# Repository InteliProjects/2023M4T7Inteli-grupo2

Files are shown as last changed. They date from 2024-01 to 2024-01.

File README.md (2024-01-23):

# Inteli - Instituto de Tecnologia e Liderança 

<p align="center">
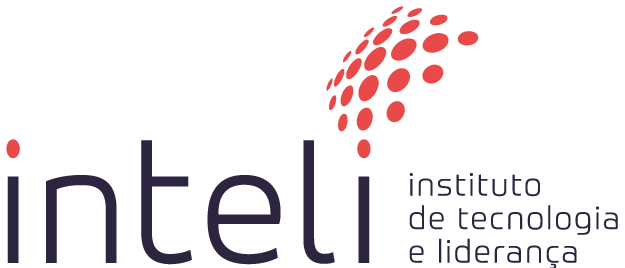
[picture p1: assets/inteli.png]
Inteli - Instituto de Tecnologia e Liderança

</p>

<br>

# Jin

## JinWar

## 👨‍🎓 Integrantes: 
- <a href="https://www.linkedin.com/in/drielly-farias/">Drielly Farias</a>
- <a href="https://www.linkedin.com/in/diogo-pelaes-a34593279/">Diogo Burgierman</a>
- <a href="https://www.linkedin.com/in/eduardo-hos/">Eduardo Henrique Oliveira Santos</a>
- <a href="https://www.linkedin.com/in/enzo-bressane-72a030219/">Enzo Schiezaro Bressane</a> 
- <a href="https://www.linkedin.com/in/isabelle-beatriz-vasquez-oliveira-55a19626a/">Isabelle Beatriz Vasquez Oliveira</a>
- <a href="https://www.linkedin.com/in/ricardo-novaes-24276b271/">Ricardo Novaes</a>

## 👩‍🏫 Professores:
### Orientador(a) 
- <a href="https://www.linkedin.com/in/profclaudioandre/">Claudio André</a>
### Instrutores
- <a href="https://www.linkedin.com/in/aila-esteque/">Aila Esteque</a>
- <a href="https://www.linkedin.com/in/andre-godoi-chiovato-83730228/">André Godoi</a> 
- <a href="https://www.linkedin.com/in/andreluizbraga/">André Braga</a> 
- <a href="https://www.linkedin.com/in/fabiana-martins-de-oliveira-8993b0b2/">Fabiana Martins de Oliveira</a>
- <a href="https://www.linkedin.com/in/fatima-toledo/">Fátima Toledo</a> 
- <a href="https://www.linkedin.com/in/geraldo-magela-severino-vasconcelos-22b1b220/">Geraldo Vasconcelos</a>
- <a href="https://www.linkedin.com/in/laizaribeiro/">Laíza Ribeiro</a>
## 📜 Descrição
&emsp;&emsp;O projeto da Alma Sírio-Libanês visa desenvolver e implementar um sistema avançado de rastreamento e gestão de movimentos para pacientes e equipes de cuidado dentro do hospital, utilizando tecnologias de localização e Internet das Coisas (IoT). A iniciativa é concentrada principalmente nas unidades de pronto-atendimento em São Paulo e Brasília, envolvendo toda a extensa rede de colaboradores e o corpo clínico do Hospital Sírio-Libanês.

&emsp;&emsp;A solução proposta busca oferecer um controle mais preciso e em tempo real da localização de pacientes e profissionais dentro da instituição, visando otimizar o fluxo de atendimento, reduzir gargalos operacionais e melhorar a eficiência dos serviços prestados, especialmente em situações de emergência. O sistema contará com etiquetas eletrônicas atribuídas aos indivíduos, permitindo sua identificação imediata, localização precisa e rastreamento de movimentos.

&emsp;&emsp;Para garantir o sucesso do projeto, uma série de fases de validação serão implementadas, abrangendo aspectos técnicos e operacionais. A intenção é assegurar que o sistema não apenas funcione corretamente do ponto de vista técnico, mas que também atenda às necessidades reais do hospital, contribuindo efetivamente para a melhoria dos processos internos.

&emsp;&emsp;O MVP (Produto Mínimo Viável) consistirá em uma ferramenta de gestão de localização de pessoas, que deverá cumprir uma série de requisitos essenciais, incluindo a identificação do portador da etiqueta e seu papel dentro da instituição, fornecimento de localização em tempo real, avaliação de tempos de permanência em áreas específicas, possibilidade de resposta a emergências e recebimento de informações críticas, além da avaliação de tempos de resposta a emergências. O dispositivo associado é ser portátil, resistente e fácil de manipular.

[Aqui](https://youtu.be/W80r4j70KOY) é possível acessar o link do vídeo com a demonstração da solução Jinwar.

[Aqui](https://miro.com/welcomeonboard/U0x3RXdwbGt4dHk1anlPYnpDbzl5alZtdFVXVk9NbmNHNzBNT25CQWt2MUxkbGhlQU9VMTM3Y2lqRUU2cFdZeHwzNDU4NzY0NTQ1NjY5NzM5MDc0fDI=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) é possível acessar o link do Lean Inceeption

## 📁 Estrutura de pastas

Dentre os arquivos e pastas presentes na raiz do projeto, definem-se:

- <b>assets</b>: aqui estão os arquivos relacionados a parte gráfica do projeto, ou seja, as imagens e vídeos que os representam (O logo do grupo pode ser adicionado nesta pasta).

- <b>document</b>: aqui estão todos os documentos do projeto, incluindo o manual de instruções (se aplicável). Há também uma pasta denominada <b>outros</b> onde estão presentes outros documentos complementares.

- <b>src</b>: Todo o código fonte criado para o desenvolvimento do projeto, incluindo firmware, notebooks, backend e frontend, se aplicáveis.

- <b>README.md</b>: arquivo que serve como guia e explicação geral sobre o projeto (o mesmo que você está lendo agora).

## 🔧 Instalação

Para utilizar a solução Jin, é ncessário ter acesso à:
- Arduino IDE (disponível no site :https://www.arduino.cc/en/software)
- Ubidots (disponível em Ubidots.com)
- 
  Em caso de dúvida sobre como instalar ou navegar por alguma das plataformas, consulte a seção 3 do manual de instruções.

**Manual de Instruções**: https://github.com/2023M4T7Inteli/grupo2/blob/main/document/Manual%20de%20Instru%C3%A7%C3%B5es%20-%20Jinwar.pdf

## 🗃 Histórico de lançamentos
* 0.0.1 - 27/10/2023
    Adição das seções 1, 3.1 correspondente à Entendimento do negócio

* 0.0.2 - 27/10/2023
    Adição das seção 3.2 correspondente à experiência de usuário

* 0.0.3 - 27/10/2023
    Adição da seção 3.4.1 correspondente ao Protótipo inicial do projeto usando o simulador wokwi

* 0.0.4 - 27/10/2023
    Adição da seção 3.3.1 correspondente aos Requisitos Funcionais

* 0.1.1 - 10/11/2023
    Adição da seção 3.2.4 correspondente a Prototipagem rápida da solução

* 0.1.2 - 10/11/2023
        Adição da seção 3.4.2 correspondente ao Protótipo físico do projeto (offline)

* 0.1.3 - 10/11/2023
        Adição da seção 3.2.2 correspondente aos Requisitos não funcionais

* 0.2.1 - 24/11/2023
        Adição da seção 3.4.3 correspondente ao Protótipo do Projeto com MQTT e I2C

* 0.2.2 - 24/11/2023
        Adição da seção 2 correspondente a metodologia RM-ODP

* 0.2.3 - 29/11/2023
        Adição da seção 3.3.4 correspondente a arquitetura técnica da solução

* 0.3.1 - 08/12/2023
        Adição da seção 3.4.4 correspondente a Protótipo Físico do Projeto (online)

* 0.3.2 - 08/12/2023
        Adição do código do projeto

* 0.3.3 - 08/12/2023
        Adição da seção 3.3.5 correspondente a Arquitetura do Protótipo

* 0.3.4 - 08/12/2023
        Adição do Manual de Instruções

* 0.3.4 - 08/12/2023
        Adição da seção 3.3.5 correspondente às Possibilidades de Descarte

* 0.4.1 - 21/12/2023
        Adição da seção 3.4.5 correspondente ao Protótipo Final do Projeto

* 0.4.2 - 21/12/2023
        Adição da versão final do código

* 0.4.3 - 21/12/2023
        Adição da seção 3.3.6 correspondente a Arqitetura Refinada da Solução

* 0.4.4 - 21/12/2023
        Atualização do Manual de Instruções

* 0.4.5 - 21/12/2023
        Revisão e ajustes finais

## 📋 Licença/License

<p xmlns:cc="http://creativecommons.org/ns#" xmlns:dct="http://purl.org/dc/terms/">
    <a property="dct:title" rel="cc:attributionURL" href="https://github.com/2023M4T7Inteli/grupo2">Jinwar</a> by 
    <span property="cc:attributionName">
        <a href="https://www.linkedin.com/in/diogo-pelaes-a34593279/">Diogo Burgierman</a>, 
        <a href="https://www.linkedin.com/in/drielly-farias/">Drielly Farias</a>, 
        <a href="https://www.linkedin.com/in/eduardo-hos/">Eduardo Henrique Oliveira Santos</a>, 
        <a href="https://www.linkedin.com/in/enzo-bressane-72a030219/">Enzo Schiezaro Bressane</a>,
        <a href="https://www.linkedin.com/in/isabelle-beatriz-vasquez-oliveira-55a19626a/">Isabelle Beatriz Vasquez Oliveira</a>, 
        <a href="https://www.linkedin.com/in/ricardo-novaes-24276b271/">Ricardo Novaes</a>
    </span> 
    is licensed under 
    <a href="http://creativecommons.org/licenses/by/4.0/?ref=chooser-v1" target="_blank" rel="license noopener noreferrer" style="display:inline-block;">
        Attribution 4.0 International
        
        
    </a>
</p>

## 🎓 Referências

Aqui estão as referências usadas no projeto:
1. ROCHA, YB. **Jinwar: a vila criada por e para mulheres no Curdistão.** 18 maio 2018. Disponível em: https://www.brasildefato.com.br/2018/05/10/jinwar-a-vila-criada-por-e-para-mulheres-no-curdistao. Acesso em: 23 out. 2023.

2. LUIZ, Jonathan. **Hospitais particulares que não prestam atendimento emergencial comentem crime.** 5 out. 2020. Disponível em: https://www.correiobraziliense.com.br/cidades-df/2020/10/4880013-direito-do-consumidor.html. Acesso em: 23 out. 2023.

3. CASAROTTO, C. (2020, 11 de dezembro). **As 5 forças de Porter: quais são elas e como entender o conjunto de fatores que influenciam no sucesso do seu negócio? rockcontent.** Disponível em: https://rockcontent.com/br/blog/5-forcas-de-porter/
   Acesso em: 24 out. 2023.

4. .RAEBURN, A. (2022, 28 de novembro). **Análise SWOT/FOFA: o que é e como usá-la (com exemplos).** asana. Disponível em: https://asana.com/pt/resources/swot-analysis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 Acesso em: 22 out. 2023.

5. SOFTWARE, Lucid. **Redirecting**. Disponível em: https://www.lucidchart.com/pages/pt/o-que-e-analise-swot. Acesso em: 24 out. 2023.

6. OSTERWALDER, A.; PIGNEUR, Y.; BERNARDES, G.; SMITH, **A. Value Proposition Design: How to Create Products and Services Customers Want. New Jersey: Wiley, 2014.4**. Acesso em: 24 out. 2023.

7. ESFERA ENERGIA. (2022, 14 de outubro). **Matriz de risco: o que é, quando usar e como montar uma tabela**. esferablog. Disponível em: https://blog.esferaenergia.com.br/gestao-empresarial/matriz-de-risco. Acesso em: 25 out. 2023.

8. ALBERTACCI, Laura. **Devo me preocupar com a LGPD?** Jus.com.br. Disponível em: https://jus.com.br/artigos/91636/devo-me-preocupar-com-a-lgpd. Acesso em: 18 out. 2023.

9. SÍRIO-LIBANÊS, Hospital. **Hospital Sírio Libanês**. 8 fev. 2021. Disponível em: https://hospitalsiriolibanes.org.br/politica-de-privacidade/. Acesso em: 18 out. 2023.

10. Salminen, J., Nielsen, L., Bahloul, M. et al. **Persona preparedness: a survey instrument for measuring the organizational readiness for deploying personas.** Inf Technol Manag (2022). Disponível em: https://doi.org/10.1007/s10799-022-00373-9 Acesso em: 19 out. 2023.

11. SIQUEIRA, A. (2022, 14 de fevereiro). **Persona: o que é, como definir e por que criar uma para sua empresa [+ exemplos práticos e um gerador].** Resultados Digitais. Disponível em: https://resultadosdigitais.com.br/marketing/persona-o-que-e/#:~:text=O%20que%20é%20persona?,,%20objetivos,%20desafios%20e%20preocupações. Acesso em: 25 out. 2023.

12. SÍRIO-LIBANÊS, Hospital. **Hospital Sírio-Libanês**. Disponível em: https://www.hospitalsiriolibanes.org.br/encontre-seu-medico/. Acesso em: 19 out. 2023.

13. SAÚDE, Portal Setor. **A definição de valor em saúde do Sírio-Libanês e os desafios dos setores público e privado - Setor Saúde.** 7 maio 2019. Disponível em: https://setorsaude.com.br/a-definicao-de-valor-em-saude-do-sirio-libanes-e-os-desafios-dos-setores-publico-e-privado/. Acesso em: 19 out. 2023.

14. SÍ­RIO-LIBANÊS, Hospital. **Hospital Sí­rio-Libanês.** Disponível em: https://www.hospitalsiriolibanes.org.br/especialidades-medicas/sao-paulo/hernia-e-parede-abdominal/. Acesso em: 19 out. 2023.

15. BRASIL, Hospitais. **Sírio-Libanês cria nova marca para fomentar tecnologia, dados e inovação na saúde e ensino.** 16 dez. 2022. Disponível em: https://portalhospitaisbrasil.com.br/sirio-libanes-cria-nova-marca-para-fomentar-tecnologia-dados-e-inovacao-no-setor-de-saude-e-ensino/. Acesso em: 19 out. 2023.

16. SÍRIO-LIBANÊS, **Hospital. Experiência Sírio-Libanês | Sírio-Libanês Ensino e Pesquisa.** Disponível em: https://iep.hospitalsiriolibanes.org.br/experiencia-sirio-libanes. Acesso em: 19 out. 2023.

17. SÍRIO-LIBANÊS, Hospital. **Especialização em Experiência do Paciente e Cuidado Centrado na Pessoa | Hospital Sírio-Libanês.** Disponível em: https://iep.hospitalsiriolibanes.org.br/cursos-pos-graduacao/especializacao-em-experiencia-do-paciente-e-cuidado-centrado-na-pessoa. Acesso em: 26 out. 2023.

18. GIBBONS, Sarah. **Journey Mapping 101.** 9 dez. 2018. Disponível em: https://www.nngroup.com/articles/journey-mapping-101/. Acesso em: 24 out. 2023.

19. TEAM, Vyond. **What Is A Storyboard & How Do You Create One? (With Video)**. 11 jan. 2023. Disponível em: https://www.vyond.com/resources/what-is-a-storyboard-and-why-do-you-need-one/. Acesso em: 19 out. 2023.

20. ARRUDA, Ricardo. **O que são User Stories (Estórias de Usuário)? - Agile Expert**. 14 maio 2021. Disponível em: https://www.agilexpert.com.br/2021/05/14/o-que-sao-user-stories-historias-de-usuario/. Acesso em: 25 out. 2023.

21. ECOASSIT. **Quais impactos o lixo eletrônico causa no planeta?** - Ecoassist. Disponível em: https://ecoassist.com.br/quais-impactos-o-lixo-eletronico-causa-no-planeta/. Acesso em: 30 nov. 2023.

22. FERREIRA, Thalita.**Quais são os impactos dos resíduos Eletrônicos no Meio Ambiente.** 15 set. 2022. Disponível em: https://matanativa.com.br/impactos-dos-residuos-eletronicos-no-meio-ambiente/#:~:text=Efeitos%20nocivos%20à%20saúde%20humana,de%20pulmão;%20e%20câncer%20linfático. Acesso em: 30 nov. 2023.

23. MARTINS, Alejandra. **O metal pesado tóxico que afeta crianças no Brasil e no mundo décadas após proibição - BBC News Brasil.** 20 jul. 2021. Disponível em: https://www.bbc.com/portuguese/geral-57886448. Acesso em: 5 dez. 2023.

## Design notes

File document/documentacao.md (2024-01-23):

# Documentação IoT - Módulo 4 - Inteli

## JinWar

#### <a href="https://www.linkedin.com/in/drielly-farias/">Drielly Farias</a>, <a href="https://www.linkedin.com/in/diogo-pelaes-a34593279/">Diogo Burgierman</a>, <a href="https://www.linkedin.com/in/eduardo-hos/">Eduardo Henrique Oliveira Santos</a>, <a href="https://www.linkedin.com/in/enzo-bressane-72a030219/">Enzo Bressane</a>, <a href="https://www.linkedin.com/in/isabelle-beatriz-vasquez-oliveira-55a19626a/">Isabelle Vasquez</a>, <a href="https://www.linkedin.com/in/ricardo-novaes-24276b271/">Ricardo B Novaes</a>

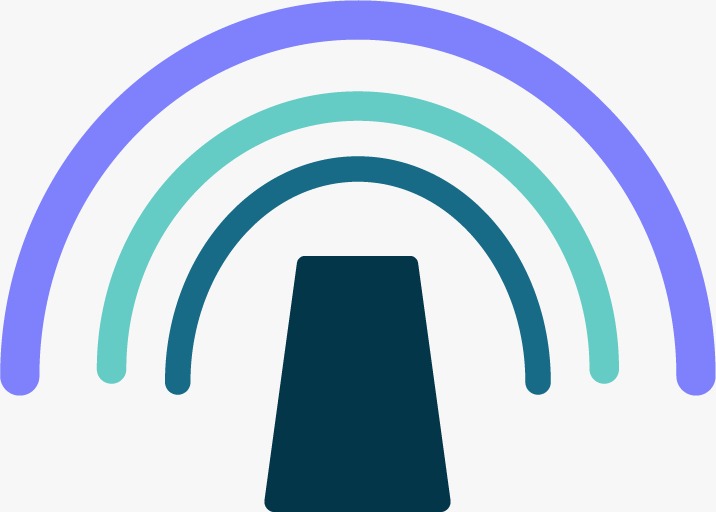
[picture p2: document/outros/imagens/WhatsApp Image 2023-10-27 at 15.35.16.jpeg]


## Sumário

[1. Introdução](#c1)

[2. Metodologia](#c2)

[3. Desenvolvimento e Resultados](#c3)

[4. Possibilidades de Descarte](#c4)

[5. Conclusões e Recomendações](#c5)

[6. Referências](#c6)

<br>

# 1. Introdução

&emsp;&emsp;Este texto descreve o contexto, desenvolvimento e evolução do projeto do grupo JinWar, o qual visa coletar, organizar e fornecer a localização de pessoas dentro do ambiente do hospital Sírio Libanês. Além de questões técnicas, são apresentadas também informações sobre a análise de negócios da empresa.

&emsp;&emsp;O hospital Sírio-Libanês começou em 1921 com um grupo de mulheres e, ao longo de mais de um século, se consolidou como hospital de referência. Atualmente é uma instituição de grande porte, com atuação na área de saúde e inovação médica, com unidades em São Paulo e Brasília.

&emsp;&emsp;A Alma Sírio-Libanês, uma divisão do Hospital Sírio Libanês com foco em tecnologia e inovação, propôs o desenvolvimento de uma solução baseada em IoT, para coletar e fornecer a localização da equipe assistencial e dos pacientes, a fim de alocar atividades e funcionários com maior eficiência. O grupo JinWar pretende solucionar a questão usando componentes de hardware e a linguagem de programação C++.

&emsp;&emsp;O grupo Jinwar¹, o qual realizou esse projeto, escolheu esse nome para representá-los por significar de acordo com uma tradução livre do dialeto curdo, kurmanji, “o espaço de vida”. Além disso, esse é o mesmo nome de uma cidade só de mulheres e crianças que busca se afastar dos conflitos.

&emsp;&emsp;A cidade é uma forma de manifestação e resposta a violência de homens jugos em conflitos na Síria. Como o Sirio-Libanês foi uma forma de gratidão de mulheres sirio-libanesas ao que a cidade de São Paulo proporcionou a elas, e que até hoje acolhe pessoas, Jinwar também é uma manifestação de acolhimento a essas famílias de mulheres que buscam se erguer com seus filhos no meio de um grande ato de sororidade. O grupo Jinwar compartilha desse mesmo espírito e busca criar um ambiente seguro, onde os indivíduos possam recorrer para cuidar de sua saúde e bem-estar.

## 1.1 Objetivos

&emsp;&emsp;O hospital deseja como objetivo geral otimizar a alocação da equipe assistencial e dos pacientes nos locais de pronto-atendimento. Desse modo, pretende-se criar um dispositivo wearable capaz de informar a localização de profissionais, com foco na equipe de enfermagem, médicos e fisioterapeutas mais próximos do paciente que precisa de assistência, de forma rápida e eficiente. Sendo mais específico, a localização poderá ser feita por meio de um crachá que auxiliaria na otimização. O dispositivo também permitirá ter uma visão macro da localização da equipe do hospital no Pronto Atendimento (PA), para então priorizar e reordenar os demais tipos de atendimentos, como consultas e exames.

## 1.2 Proposta da solução

&emsp;&emsp;A solução para o problema descrito será um sistema com o uso de uma tag com RFID (Radio Frequency Identification), usando uma placa Arduino EESP 32, um kit RFID-RC522 e uma interface para visualização dos dados coletados.
Esses componentes de hardware serão integrados usando a linguagem de programação C++ e C.

## 1.3 Justificativa

&emsp;&emsp;O sistema Jinwar otimiza o atendimento e dinâmica diária no hospital ao acelerar a troca de informações entre equipes e centralizar as informações de localização disponíveis em um único lugar. A agilidade que o Jinwar proporciona permite direcionar o fluxo de atendimento do paciente e diminuir o tempo de resposta por parte da equipe médica. Além disso, possui baixo custo de implementação. O foco macro do projeto visa conseguir preservar a vida. Com os benefícios que esse projeto traz, o Hospital Sirio-Libanês, com a sua vertical de inovação Alma - Sirio-Libanês poderá ser uma solução única feita pensada para auxiliar a equipe médica que precisa ser objetiva no atendimento. Pontos como o estacionamento do hospital não são passíveis de obter a localização precisa sobre onde o paciente está ou sobre onde a equipe do hospital está para auxiliar. Com essa solução, esse tipo de problema, caso venha a acontecer, não terá empecilhos por falta de alcance.

# 2. Metodologia

&emsp;&emsp;O Modelo de Referência para Arquitetura Orientada a Objeto, ou RM-ODP (Reference Model for Open Distributed Processing) é um framework padronizado que define uma abordagem para o design de sistemas complexos, como projetos de IoT em grande escala. Ele foca em aspectos como estrutura, comportamento e interações entre diferentes partes de um sistema. O RM-ODP destaca-se por sua abordagem abrangente e flexível na descrição de arquiteturas de sistemas. Sua padronização, aceita por organizações de referência, promove a consistência e interoperabilidade em ambientes que adotam esse modelo. Além disso, o modelo é especialmente adequado para a programação orientada a objetos, sendo uma escolha ideal para projetos de IoT.

&emsp;&emsp;Na execução de cada etapa da metodologia aplicada, é fundamental evidenciar os seguintes pontos:

- **Ponto de Vista da Empresa:** Foca na identificação dos requisitos do negócio, objetivos, e políticas organizacionais. Esta etapa é crucial para compreender o contexto dentro do qual o sistema irá operar e os objetivos que ele visa atingir. Neste ponto, definimos a proposta de solução seguindo os objetivos da instituição e as prioridades do cliente. A análise feita para decidir esses pontos foi feita a partir de análises de negócios como Canvas Proposta de Valor, Análise SWOT, 5 Forças de Porter e Matriz de Riscos, com o objetivo de entender como a solução vai impactar nos processos do hospital e as melhores formas de otimizar os mesmos.

- **Ponto de Vista da Informação:** Concentra-se na estrutura e no fluxo de informações dentro do sistema. Esta etapa envolve a modelagem dos tipos de dados que o sistema irá processar, bem como as regras e restrições sobre esses dados. Para isso, o grupo buscou entender como os dados são distribuídos atualmente e como será esse fluxo de informações na solução. Essa análise envolveu coletar informações sobre requisitos para a gestão de informação, estrutura de dados e interface.

- **Ponto de Vista da Computação:** Esta etapa aborda a funcionalidade do sistema, definindo os componentes de software que irão realizar as operações e processos necessários. Inclui a modelagem das interfaces e a interação entre os componentes se software e hardware. Para isso, definimos os componentes de hardware essenciais e como o ESP32, sensores de RFID e Tokens de RFID, além de outros componentes relacionados aos mesmos. Por outro lado, entre os componentes de software essenciais estão o uso do protocolo de comunicação MQTT para possibilitar a comunicação e alta velocidade de resposta entre os componentes da solução.

- **Ponto de Vista da Engenharia:** Foca na infraestrutura necessária para suportar a distribuição do sistema. Esta etapa lida com a arquitetura do sistema em termos de componentes de software e hardware, comunicação de rede, e mecanismos de controle e gerenciamento. No desenvolvimento do projeto, o grupo definiu os componentes de hardware na seção de Bill Of Materials e definiu o Ubdots como uma plataforma necessária para realizar a comunicação de rede entre os componentes físicos e o software já que a plataforma Ubidots proporciona uma integração rápida, possibilitando uma interação com a solução por meio de uma interface de forma prática. Além disso, foram definidas abordagens para o desenvolvimento e implementação, incorporando as particularidades da solução sugerida.

- **Ponto de Vista da Tecnologia:** Esta etapa envolve a seleção de tecnologias específicas, ferramentas e plataformas que serão utilizadas na implementação do sistema. Inclui a escolha de linguagens de programação, sistemas de banco de dados, hardware, e outras tecnologias relevantes. No caso do projeto desenvolvido pelo grupo Jinwar, foram selecionadas tecnologias como o ESP32, RFID, MQTT que serão implementadas por outros componentes de hardware e por códigos desenvolvidos na linguagem C++. Para realizar essa decisão, foi analisada a viabilidade de infraestruturas de redes e as melhores opções de protocolos de comunicação, pensando tanto na funcionalidade quanto na segurança no contexto de localização de pessoas em um ambiente hospitalar.

&emsp;&emsp;Esses cinco pontos de vista da **RM-ODP** oferecem uma estrutura abrangente para o planejamento e design de sistemas distribuídos, assegurando que todos os aspectos críticos, desde os objetivos de negócios até as escolhas tecnológicas, sejam cuidadosamente considerados e integrados.

&emsp;&emsp;É crucial ressaltar que este modelo é independente de tecnologia. As descrições de arquitetura no RM-ODP são conceituais e não estão vinculadas a tecnologias específicas, o que favorece a adaptabilidade do sistema ao longo do tempo. Todos esses motivos levaram o grupo Jimwar a adotar o modelo RM-ODP no desenvolvimento da solução IoT para o Hospital Sírio-Libanês.

# 3. Desenvolvimento e Resultados

&emsp;&emsp; Nesta seção, encontra-se o registro de desenvolvimento do projeto, documentando as informações sobre a análise de negócios, sobre o design da experiência do usuário e os resultados obtidos a partir desse estudo juntamente com a aplicação dos conhecimentos técnicos.

## 3.1. Domínio de Fundamentos de Negócio

&emsp;&emsp;Nesta seção, busca-se entender qual é o contexto do projeto e da indústria, onde Alma Sirio Libanes se situa no mercado, apresentando a solução, seus pontos que agregam valor, no que ela se diferencia, buscando ter uma visão micro e ao mesmo tempo macro do parceiro e da solução. Dessa maneira, a solução Jinwar poderá ser construída com mais segurança, se preparando para eventuais problemas, oportunidades, e até mesmo, para como serão tratados os dados dos pacientes e equipe do hospital.

### 3.1.1. Contexto da Indústria

&emsp;&emsp;Nos últimos anos, a indústria de saúde no Brasil tem passado por grandes transformações, tanto no que se refere à inovação tecnológica quanto na redefinição do foco do atendimento, ao mesmo tempo em que enfrenta desafios constantes relacionados às regulamentações governamentais.

&emsp;&emsp;É inegável que a indústria de hospitais particulares no Brasil tem experimentado um notável crescimento, o que gera uma competição acirrada entre as principais empresas do setor e uma busca crescente por vantagens competitivas. No cenário atual, a inovação tecnológica se tornou o pilar central dessa expansão, implicando a necessidade de mais investimentos e pesquisas por parte de hospitais renomados, como o Hospital Sírio-Libanês. Isso ocorre porque a adoção de novas tecnologias em ambientes de alto risco, que têm um impacto direto na saúde das pessoas, requer padrões de qualidade excepcionais, sendo a vida tratada como ponto mais vultoso.

&emsp;&emsp;O setor de saúde no Brasil enfrenta desafios significativos relacionados a questões regulatórias, uma vez que esse sistema é altamente regulamentado, com normas que variam desde a construção e operação de hospitais até as diretrizes para a prática médica e aquisição de equipamentos. Além disso, o financiamento da saúde no Brasil é um desafio constante. Os hospitais particulares dependem em grande parte de receitas provenientes de planos de saúde, que nem sempre são suficientes para cobrir os crescentes custos dos serviços médicos². É importante ressaltar que o sistema de saúde pública, o Sistema Único de Saúde (SUS), enfrenta limitações orçamentárias, o que pode aumentar a pressão sobre o setor privado para atender às necessidades de saúde da população.

&emsp;&emsp;Em um país de grande extensão territorial, com uma desigualdade social tão significativa como o Brasil, esse mesmo cenário se reflete na prestação de serviços de saúde. Enquanto as grandes cidades e áreas urbanas tendem a ter hospitais bem equipados e serviços de alta qualidade, as áreas rurais e regiões mais remotas frequentemente enfrentam carências de infraestrutura médica e escassez de profissionais de saúde. Essa desigualdade pode sobrecarregar hospitais particulares em áreas de maior demanda e pressionar ainda mais o sistema de saúde, até mesmo por questões governamentais reguladas, como a obrigatoriedade dos hospitais privados de prestar serviço emergencial ², caso contrário é considerado crime.

&emsp;&emsp;Nesse cenário de constantes mudanças, o setor de saúde privado enfrenta a responsabilidade de fornecer serviços de alta qualidade, promover a equidade no acesso e desempenhar um papel crucial na construção de um sistema de saúde mais robusto e acessível para toda a população brasileira.

#### 3.1.1.1. Cinco Forças Poter

&emsp;&emsp;Na contextualização da indústria, a análise das 5 Forças de Porter³ é de suma importância, sendo um modelo fundamental para compreender a competitividade de um mercado. Desenvolvido por Michael Porter na década de 1970, esse framework é amplamente utilizado na administração, auxiliando as empresas na elaboração de estratégias eficazes que consideram o modelo de negócios. O modelo se concentra em cinco forças-chave que moldam um setor de negócios: a rivalidade entre concorrentes, o poder de barganha dos fornecedores, o poder de barganha dos compradores, a ameaça de novos entrantes e a ameaça de produtos ou serviços substitutos. Cada uma dessas forças desempenha um papel significativo na determinação do sucesso e da lucratividade de um negócio. Portanto, compreender e aplicar as 5 Forças de Porter é essencial para o planejamento estratégico, como evidenciado no projeto Jinwar, onde se esquematizou as 5 forças em relação à digitalização no setor de saúde, visando posicionar o Alma Sírio-Libanês de maneira competitiva no mercado em constante evolução.

<div align="center">
  <p> <b>Figura 01</b> - Cinco Forças Porter 1 </p>
  Cinco Forças Porter1
  <p><b>Fonte:</b> elaboração por Jinwar.</p>
</div>

<div align="center">
  <p> <b>Quadro 01</b> - Cinco Forças Porter 2 </p>

| Forças | Quem são | Quais ameaças | Quais as minhas reações possíveis |
| --- | --- | --- | --- |
| **F1 - Concorrentes atuais** | Hospital Albert Einstein, Hospital Samaritano Paulista, Hospital Alemão Oswaldo Cruz, Hospital Beneficência Portuguesa | **Hospital Israelita Albert Einstein:** possui vários projetos envolvendo soluções de saúde digital e tecnologia para suporte ao paciente e ao médico, juntamente com a gestão do fluxo de pacientes no ambiente de emergência; Hospital Samaritano Paulista: tem se empenhado na implementação de fluxos de dados e processos uniformes, com foco em emergência; **Hospital Alemão Oswaldo Cruz:** implementou a tecnologia IoT para monitoramento de temperatura e umidade. Há também menção a um projeto de Inteligência de Negócios para melhorar a análise de dados, e o hospital abriga um Centro de Inovação e Educação possivelmente envolvido em projetos sobre emergência via IoT; **Hospital Beneficência Portuguesa:** participou de um Projeto Lean focado na gestão de fluxo de processos em vários departamentos, incluindo o departamento de emergência. Além disso, um projeto de videomonitoramento foi mencionado, mas não foram fornecidos detalhes específicos sobre IoT. | Priorizar inovação e pesquisa, buscar padrões superiores de atendimento e melhorar a tecnologia. |
| **F2 - Conconrrentes Potenciais** | Startups e empresas emergentes no setor de tecnologia da saúde, Centro de Inovação Tecnológica (CIT) - Albert Einstein, Hospital das clinicas de São Paulo, Hospital São Luiz. | **Health Innovation Techcenter (HIT):** pode estar envolvido em projetos de inovação que também visam melhorar a eficiência e a qualidade dos serviços hospitalares, incluindo soluções de IoT para saúde; **Hospital das Clínicas de São Paulo:** implementou a tecnologia 5G, permitindo avanços em diversas áreas, incluindo a saúde. Esta tecnologia pode servir como uma base para a implementação de soluções IoT para gestão de fluxo de pacientes; **Hospital São Luiz:** possui uma infraestrutura equipada com tecnologia de ponta, indicando uma possível inclinação para a implementação de soluções tecnológicas avançadas, como IoT, para gestão de fluxo de pacientes. | Fomentar parcerias estratégicas, manter-se atualizado sobre inovações e expandir a oferta de soluções. |
| **F3 - Produtos substitutos** | Tecnologias de saúde alternativas, Soluções de home care, Smart Watches. | Deslocamento do foco do ambiente hospitalar tradicional; solução não centrada no corpo hospitalar. | Diversificar portfólio, integrar soluções de home care e aprimorar o atendimento virtual. |
| **F4 - Fornecedores** | Empresas que fornecem tecnologias avançadas, materiais e softwares para o Alma Sírio-Libanês, WJ Componentes Eletrônicos, MakerHero. | Dependência de tecnologias específicas ou escassez de materiais, Precificação alta por demanda. | Criar acordos estratégicos, explorar novos parceiros tecnológicos e otimizar processos de compra. |
| **F5 - Clientes** | **Pacientes do Hospital Sírio-Libanês**: pessoas de classe média a alta, com condição de pagar a mensalidade; | Falta de fidelidade na contratação do serviço de saúde. | Oferecer diferentes planos, que se adequem às necessidades de cada perfil. |

  <p><b>Fonte:</b> elaboração por Jinwar.</p>
</div>

&emsp;&emsp;Ao avaliar o cenário em que o Alma Sírio-Libanês está inserido, torna-se evidente a necessidade de uma estratégia dinâmica e proativa para enfrentar os desafios emergentes. A combinação de concorrência acirrada, evolução tecnológica e expectativas elevadas dos clientes exige uma postura inovadora e centrada no usuário. O futuro do setor de saúde é digital, e o "Alma Sírio-Libanês" está, sem dúvida, na vanguarda dessa transformação. Analisando o contexto, o Hospital Sírio-Libanês deve considerar a concorrência atual, como o Hospital Albert Einstein, Samaritano Paulista, Alemão Oswaldo Cruz e Beneficência Portuguesa como os maiores concorrentes. As ameaças incluem o avanço tecnológico e a busca por inovação desses concorrentes, levando o Sírio-Libanês a reagir com aprimoramento em soluções de saúde digital e gestão de fluxo de pacientes.

&emsp;&emsp;Ademais, os concorrentes potenciais, como startups e instituições como o Hospital das Clínicas de São Paulo, representam a introdução rápida de novas tecnologias no mercado, exigindo que o Sírio-Libanês fomente parcerias estratégicas e esteja atualizado sobre inovações.

&emsp;&emsp;A ameaça dos produtos substitutos, como tecnologias alternativas e soluções de home care, requer a diversificação do portfólio e a integração de soluções de home care para manter o foco no ambiente hospitalar tradicional.

&emsp;&emsp;Os fornecedores, incluindo empresas de tecnologia e materiais, podem apresentar desafios de dependência e precificação. Portanto, o Sírio-Libanês deve buscar acordos estratégicos, para explorar novos parceiros e otimizar processos de compra.

&emsp;&emsp;Por fim, as expectativas crescentes dos pacientes e a demanda por soluções personalizadas e eficientes destacam a necessidade de melhorar o atendimento e adaptar-se às necessidades do cliente, visando fornecer um atendimento premium. A todo modo é perceptível que a solução que se trata, Jinwar, para o Hospital Sirio-Libanes é única, o que proporciona o desenvolvimento de um mercado original. No mundo dos negócios, esse mercado é chamado de Oceano Azul.

### 3.1.2. Análise SWOT

&emsp;&emsp;A Matriz SWOT⁴, conforme descrita por Albert Humphrey⁵, é uma ferramenta visual de análise utilizada para identificar pontos fortes e fracos em cenários tanto pessoais quanto profissionais. Seu propósito principal é facilitar a tomada de decisões e o planejamento futuro. Essa matriz aborda aspectos específicos de uma organização, englobando suas Forças (Strengths - S), Fraquezas (Weaknesses - W), Oportunidades (Opportunities - O) e Ameaças (Threats - T), conforme as siglas em inglês.

&emsp;&emsp;A Matriz SWOT é aplicada quando gestores buscam uma compreensão mais ampla dos fatores que podem influenciar o rumo de suas trajetórias. Ela auxilia na identificação de recursos já disponíveis e fornece uma visão mais clara das dificuldades e desafios que podem surgir no horizonte. Dessa forma, as organizações conseguem avaliar com precisão suas competências e áreas de aprimoramento, bem como tomar decisões estratégicas para aprimorar sua posição competitiva e alcançar os objetivos de negócios estabelecidos.

<div align="center">
  <p> <b>Figura 02 </b> - Análise SWOT</p>
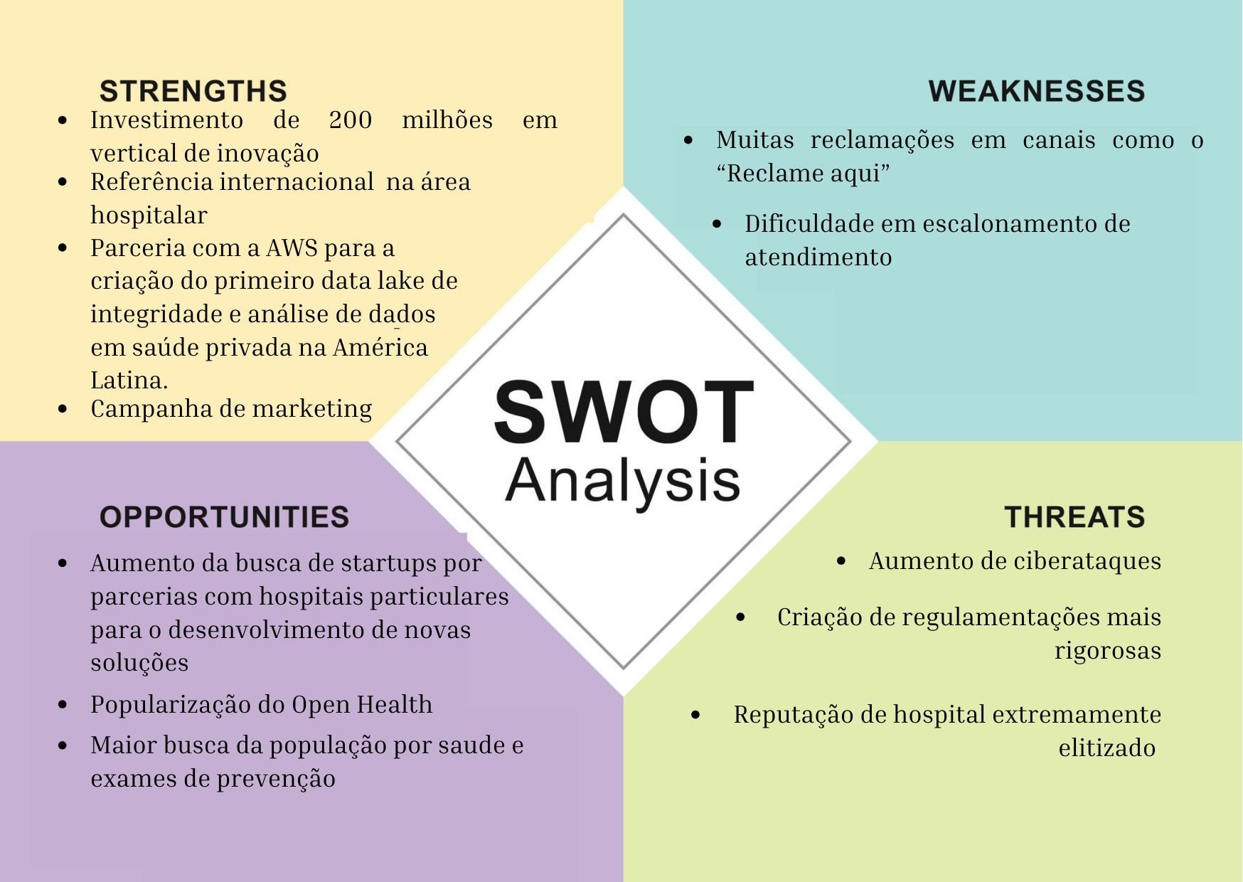
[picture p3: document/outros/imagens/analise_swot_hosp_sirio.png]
Análise SWOT
  
  <p><b>Fonte:</b> elaboração própria</p>
</div>

&emsp;&emsp;Ao realizar a análise SWOT, é necessária a avaliação de diversos aspectos relacionados à empresa em questão. O Hospital Sírio-Libanês se destaca no quesito de forças, pois a empresa tem investido significativamente em inovação e tecnologia, como a nova vertical de inovação, tecnologia e dados em saúde chamada Alma Sírio-Libanês. O Hospital Sírio-Libanês é classificado como o segundo melhor hospital do Brasil e o 104º melhor hospital do mundo. Além disso, nos últimos meses, estabeleceu uma parceria com a AWS (Amazon Web Services) para desenvolver o primeiro data lake de integridade e análise de dados em saúde privada na América Latina.

&emsp;&emsp;Por outro lado, a integração do hospital com tecnologias modernas o torna mais suscetível a ciberataques, uma vez que as infraestruturas digitais expandem as superfícies de ataque. Isso é particularmente preocupante para organizações que lidam com dados altamente sensíveis, como as informações dos pacientes de um hospital.

&emsp;&emsp;Ademais, a crescente dependência de sistemas de registros médicos eletrônicos, dispositivos médicos conectados à Internet e a troca de informações de saúde via redes digitais aumenta as oportunidades para potenciais invasores explorarem vulnerabilidades. Diante disso, a segurança cibernética torna-se uma prioridade crítica para garantir a integridade e disponibilidade dos dados de saúde, bem como a continuidade dos serviços de cuidados de saúde. Portanto, os hospitais precisam implementar medidas rigorosas de proteção cibernética e estar preparados para enfrentar ameaças cada vez mais sofisticadas.

### 3.1.3. Descrição da Solução a ser Desenvolvida

&emsp;&emsp;O objetivo dessa seção é conseguir identificar o problema, a forma de se atuar em cima dele. Explicando a solução em seus detalhes e até mesmo critérios de avaliação da solução.

#### 3.1.3.1 Qual é o problema a ser resolvido

&emsp;&emsp;Hospitais costumam ter problemas com fluxo de pessoas e organização justamente por não saber em que fase de atendimento cada paciente está e quanto tempo está sendo gasto em cada uma delas. No caso de um hospital de grande porte,como o Hospital Sírio-Libanês, existe a necessidade de otimizar o atendimento e o fluxo de pessoas em áreas de urgências constantes como a unidade de pronto atendimento.

#### 3.1.3.2 Qual a solução proposta (visão de negócios)

&emsp;&emsp;A solução tem o objetivo principal de localizar cada paciente e cada colaborador da unidade de Pronto Atendimento, com foco na equipe de enfermagem, médicos e fisioterapeuta por meio de RFID (Radio Frequency Identification) integrado a um sistema que mostre o tempo médio que está sendo gasto em diferentes ambientes e fases de atendimento do Pronto Atendimento.

#### 3.1.3.3 Como a solução proposta deverá ser utilizada

&emsp;&emsp;A solução usada pelos pacientes será implementada por um adesivo que pode ser colocado tanto na pulseira de identificação do paciente quanto na região superior de uma camiseta, por exemplo. Esse adesivo será uma etiqueta RFID que vai transmitir dados para a antena mais próxima do paciente. A mesma tecnologia será utilizada pelos colaboradores do hospital, porém por uma questão de necessidades inegociáveis desses profissionais (como manter as mãos sempre higienizadas e evitar adereço nos pulsos/braços) os mesmos utilizaram um crachá similar a um cartão comum com o chip de RFID.

&emsp;&emsp;É importante se atentar que pode ser necessário instalar novas antenas e leitores de RFID caso não a distribuição de antenas do hospital não seja suficientemente precisa para o cliente, por isso é necessário já considerar isso como um gasto provável.

&emsp;&emsp;Após o leitor se conectar a antena e receber as informações do RFID do usuário, esses dados serão enviados para um computador com a base de dados RFID que vai armazenar e avaliar esses dados.

#### 3.1.3.4 Quais os benefícios trazidos pela solução proposta

&emsp;&emsp;Os principais benefícios providos pela solução que o grupo Jinwar envolvem são o baixo custo da implementação desse sistema e a precisão da localização de cada pessoa que estiver no ambiente hospitalar.

&emsp;&emsp;Além de otimizar o tempo e o fluxo de pessoas no ambiente, essa solução também proporciona mais segurança para os pacientes e colaboradores, já que você consegue identificar rapidamente a rota que cada pessoa fez e encontrá-la rapidamente em casos de emergência.

#### 3.1.3.5 Qual será o critério de sucesso e qual medida será utilizada para o avaliar

&emsp;&emsp;O sucesso da implementação de um dispositivo de rastreamento de localização em um pronto atendimento depende da precisão na localização, otimização do fluxo de pacientes e redução no tempo de atendimento e espera. Esses critérios se alinham com a necessidade de garantir que os pacientes recebam cuidados mais rápidos e eficazes, enquanto também avaliam a aceitação do dispositivo. A eficácia será avaliada por métricas quantitativas, como a redução no tempo de espera e aumento na eficiência operacional, bem como qualitativamente, por meio de pesquisas de feedback para medir a satisfação e confiança dos pacientes e acompanhantes em relação ao dispositivo.

### 3.1.4. Value Proposition Canvas

&emsp;&emsp;Traduzindo o nome para portugues, “Tela de Proposta de Valor” é um tipo de documento de negócios que faz parte de uma projeção mais complexa de um outro modelo, chamado Business Model Canvas, que auxilia na análise do negócio. Nele é feito uma análise do cliente observando seus ganhos, tarefas e dores, justamente pensando no produto que está sendo gerado, desenvolvendo os aliviadores de dor, qual o serviço que o produto proporciona e quais são os criadores de ganhos⁶. Dessa forma, é possível visualizar o diferencial da solução e garantir o sucesso do modelo IoT que está sendo desenvolvido. Dito isso, segue o Canvas Proposta de valor do projeto JinWar.

<div align="center">
  <p> <b>Figura 03</b> - Canvas Proposta de Valor</p>
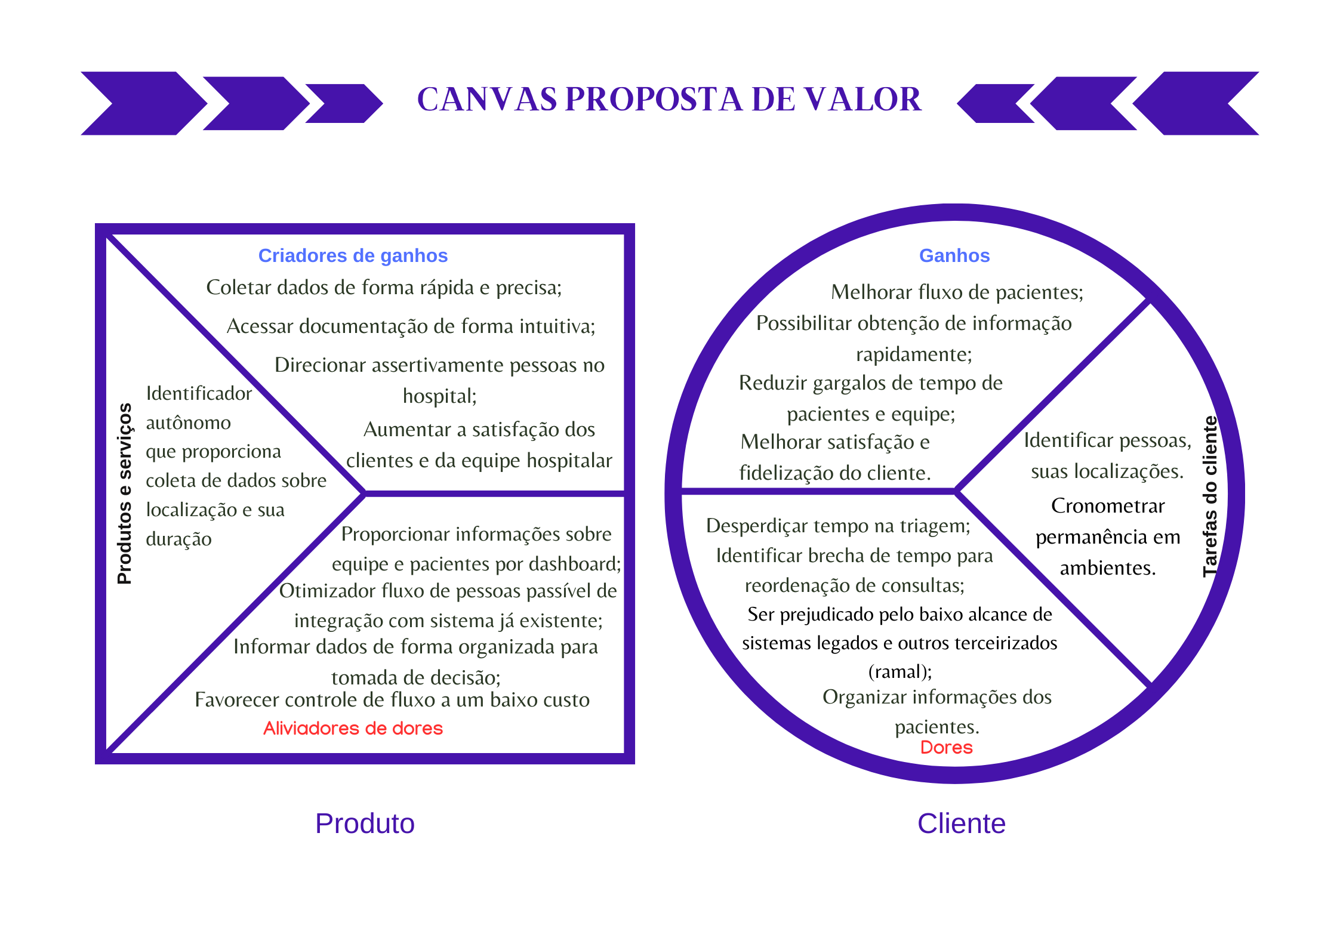
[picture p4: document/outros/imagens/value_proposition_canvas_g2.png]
Canvas Proposta de Valor
  
  <p><b>Fonte:</b> elaboração JinWar</p>
</div>

&emsp;&emsp;Analisando as imagens, vê-se como os títulos da mesma cor de produto e de cliente se relacionam. O cliente por exemplo possui a “dor” de prevenir o desperdício de tempo na triagem, como relatado em reunião com o cliente, um terço (⅓ ) do tempo do paciente é em triagem e burocracias até conseguir ser atendido. Para solucionar essa dor, há o “remédio” que o produto consegue fornecer otimizando o fluxo de pessoas dentro do hospital, através de uma dashboard informativa e organizada, facilitando a tomada de decisão. Existe os “ganhos” do cliente e os “criadores de ganhos” em produtos. Exemplificando novamente, no criador de "ganho"coletar dados de forma rápida e precisa proporciona o ganho de “possibilitar obtenção de informação rapidamente". E por último na “tarefa do cliente” existe a necessidade de identificar pessoas, suas localizações e cronometrar sua permanência em ambientes. Essa tarefa é atendida por meio de um identificador autônomo que proporciona coleta de dados sobre localização e sua duração. Seguindo essa lógica de leitura da imagem, é possível identificar o objetivo central desse Canvas Proposta de Valor, que é mostrar como o produto apresenta diferenciais que conseguem agregar valor ao cliente.

### 3.1.5. Matriz de Riscos

&emsp;&emsp;A matriz de risco⁷ é uma forma dinâmica de conseguir analisar quais são os riscos que cercam uma empresa/projeto, como a solução Jinwar. Ela é importante para conseguir gerir e prever potenciais riscos, podendo eles serem vistos como ameaça, que causa impacto negativo, ou como uma oportunidade, que causa impacto positivo. Essa dupla visão é necessária para se preparar mediante qualquer situação. É comum prever uma possível crise, e é necessário se preparar para ela, mas tão importante quanto, é se preparar para impactos positivo, como por exemplo, uma oportunidade para uma empresa de crescimento repentino exponencial devido uma solução gerar o crescimento de seu superávit. No entanto, se não existir um plano de ação que permita uma base sólida de negócio, essa oportunidade de desenvolvimento excepcional pode ser perdida. Por isso, junto da matriz de risco é feito o plano de ação para cada possibilidade.

&emsp;&emsp;Veja a seguir a matriz do projeto Jinwar:

<div align="center">
  <p><b>Figura 04 </b>- Matriz de Risco </p>
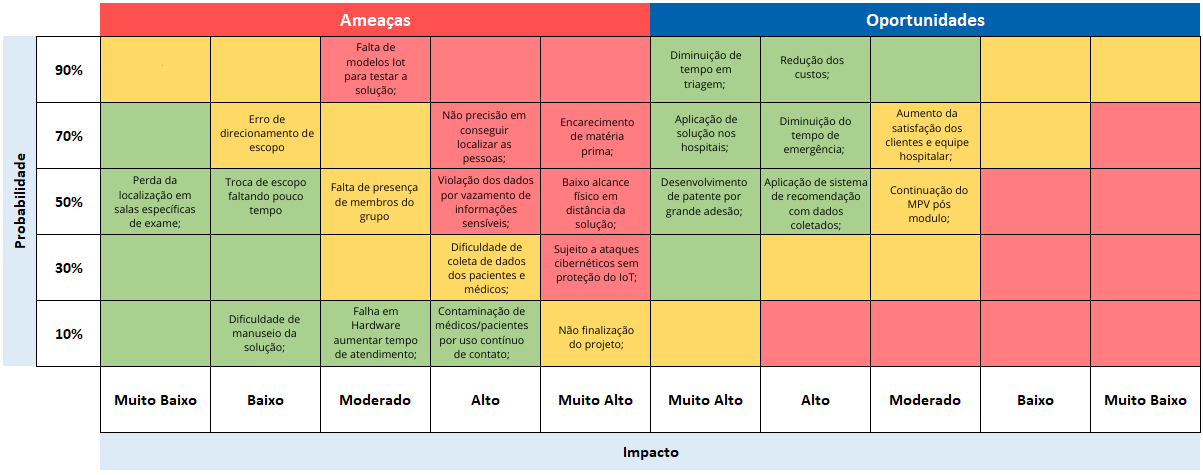
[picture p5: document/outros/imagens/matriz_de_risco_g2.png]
Matriz de Risco
  
  <p>Fonte: elaboração própria</p>
</div>

&emsp;&emsp;Analisando então a imagem de forma mais clara, abaixo a seguir é possível verificar a transcrição dos riscos existentes e a partir deles, é elaborada objetivamente a possibilidade de planos de ação. Dessa forma, é possível dar evidência ao crucial e preparar o “solo” da empresa para um projeto eficiente e embasado.

&emsp;&emsp;**Ameaças potenciais:**
- Não finalização do projeto (Probabilidade:10% X Impacto: Muito Alto);
- Contaminação de médicos/pacientes por uso contínuo de contato(Probabilidade:10% X Impacto:Alto) ;
- Dificuldade de coleta de dados dos pacientes e médicos (Probabilidade: 30% X Impacto: Alto);
- Não precisão em conseguir localizar as pessoas (Probabilidade:70 % X Impacto:);
- Falta de modelos Iot para testar a solução (Probabilidade: 90% X Impacto: Moderado);
- Dificuldade de manuseio da solução (Probabilidade: 10% X Impacto: Baixo);
- Perda da localização em salas específicas de exame (Probabilidade: 50% X Impacto:Muito Baixo);
- Troca de escopo faltando pouco tempo (Probabilidade: 50% X Impacto: Baixo)
- Falta de presença de membros do grupo (Probabilidade: 50% X Impacto: Moderado)
- Violação dos dados por vazamento de informações sensíveis (Probabilidade: 50% X Impacto: Alto);

&emsp;&emsp;**Ameaças reais:**
- Baixo alcance físico em distância da solução (Probabilidade: 50% X Impacto: Muito alto);
- Contaminação de médicos/pacientes por uso contínuo de contato (Probabilidade: 10% X Impacto: Alto);
- Sujeito a ataques cibernéticos sem proteção do IoT (Probabilidade: 30% X Impacto:Muito Alto);
- Falha em Hardware aumentar tempo de atendimento (Probabilidade: 10% X Impacto:Moderado);
- Encarecimento de matéria prima (Probabilidade: 70% X Impacto: Muito Alto);

&emsp;&emsp;**Oportunidades potenciais:**
- Desenvolvimento de patente por grande adesão (Probabilidade: 50% X Impacto: Muito Alto);
- Aplicação de sistema de recomendação com dados coletados (Probabilidade: 50% X Impacto: Alto);
- Aumento da satisfação dos clientes e equipe hospitalar (Probabilidade: 70% X Impacto: Moderado); 

&emsp;&emsp;**Oportunidades reais:**
- Aplicação de solução nos hospitais (Probabilidade: 70% X Impacto: Muito Alto); 
- Continuação do MPV pós modulo (Probabilidade: 50% X Impacto: Moderado); 
- Diminuição de tempo em triagem (Probabilidade: 90% X Impacto: Muito Alto); 
- Diminuição do tempo de emergência (Probabilidade: 70% X Impacto: Alto); 
- Redução dos custos (Probabilidade: 90% X Impacto: Alto);

&emsp;&emsp;Por fim, tendo a visão panorâmica sobre os riscos que são ameaças e oportunidades, existe a estruturação do Plano de ação em resposta para todos os riscos.Veja-os a seguir:

**Plano de Ameaças Potenciais:**

- **Não finalização do projeto:** Aplicar um cronograma realista e detalhado, com entregas claras, e monitorar o progresso regularmente com o uso de metodologias ágeis como Scrum, Kanban e técnicas como Lean Inception. Alocar recursos suficientes e contingências para possíveis imprevistos. Comunicar-se com os stakeholders e obter feedbacks constantes.

- **Contaminação de médicos/pacientes por uso contínuo de contato:** Seguir protocolo de higienização e esterilização. Usar materiais de fácil higienização na produção e encapsulamento do protótipo

- **Dificuldade de coleta de dados dos pacientes e médicos:** Estabelecer uma metodologia de coleta de dados que seja ética, segura e eficiente. Obter consentimento informado dos participantes e garantir a confidencialidade dos dados com LGPD. Utilizar ferramentas tecnológicas que facilitem a captura, armazenamento e análise dos dados.

- **Não precisão em conseguir localizar as pessoas:** Testar e validar a precisão do sistema de localização antes de implementá-lo. Verificar se há interferências ou obstáculos que possam afetar o sinal. Calibrar o sistema periodicamente e corrigir eventuais falhas.

- **Falta de modelos IoT para testar a solução:** Verificar possibilidade de expansão de orçamento para compra de mais materiais que possibilitem uma amostra maior de equipamentos. Realizar testes pilotos e simulações para avaliar o desempenho dos modelos.

- **Dificuldade de manuseio da solução:** Desenvolver uma proposta amigável e intuitiva para os usuários. Oferecer guia e materiais de apoio para os médicos e pacientes que utilizarão a solução. Além disso, obter feedbacks e sugestões de melhoria.

- **Perda da localização em salas específicas de exame:** Identificar as causas da perda de sinal e buscar soluções alternativas. Pesquisar soluções como instalar repetidores ou antenas para ampliar a cobertura. Orientar os usuários sobre como proceder em caso de perda de localização.
- **Troca de escopo faltando pouco tempo:** Planejar requisitos básicos e essenciais que independem dos requisitos funcionais, garantindo qualidade e flexibilidade para possíveis mudanças.

- **Violação dos dados por vazamento de informações sensíveis:** Reforçar as medidas de segurança da informação. Monitorar constantemente as atividades e acessos aos dados. Reportar e investigar qualquer suspeita ou incidente de vazamento.

**Plano de Ameaças Reais:**

- **Baixo alcance físico em distância da solução:** Dimensionar adequadamente o alcance da solução de acordo com as necessidades do projeto. Utilizar equipamentos e tecnologias que permitam uma maior distância sem perda de qualidade. Verificar se há barreiras físicas ou ambientais que possam reduzir o alcance.

- **Contaminação de médicos/pacientes por uso contínuo de contato:** Adotar medidas de higiene e desinfecção dos equipamentos e dispositivos utilizados na solução. Fornecer equipamentos de proteção individual (EPI) para os profissionais de saúde. Orientar os pacientes sobre como evitar a contaminação por contato.

- **Sujeito a ataques cibernéticos sem proteção do IoT:** Implementar um sistema de proteção do IoT que inclua firewall, antivírus, VPN e atualizações constantes, se possível. Realizar testes de vulnerabilidade e auditorias periódicas. Treinar os usuários sobre como prevenir e detectar ataques cibernéticos.

- **Falha em Hardware aumentar tempo de atendimento:** Realizar manutenções preventivas e corretivas nos equipamentos e dispositivos utilizados na solução. Ter um estoque reserva ou um plano de contingência em caso de falha ou quebra. Registrar e analisar as causas das falhas e buscar soluções definitivas.

- **Encarecimento de matéria prima:** Fazer uma pesquisa de mercado e buscar fornecedores alternativos que ofereçam preços mais competitivos. Renegociar os contratos e condições de pagamento com os fornecedores atuais. Buscar formas de reduzir o consumo ou substituir a matéria-prima por outras mais baratas, quando possível.

**Plano de Oportunidades Potenciais:**

- **Desenvolvimento de patente por grande adesão:** Pesquisar e verificar se a solução é inovadora e original, e se atende aos requisitos legais para obter uma patente. Contratar um especialista em propriedade intelectual para auxiliar no processo de registro da patente. Divulgar e promover a solução no mercado e na mídia.

- **Aplicação de sistema de recomendação com dados coletados:** Desenvolver um algoritmo de recomendação que utilize os dados coletados dos pacientes e médicos para oferecer soluções personalizadas e otimizadas. Testar e validar o sistema de recomendação com um grupo de usuários. Avaliar os resultados e o impacto do sistema na qualidade do atendimento.

- **Aumento da satisfação dos clientes e equipe hospitalar:** Realizar pesquisas de satisfação com os clientes e a equipe hospitalar que utilizam a solução. Identificar os pontos fortes e fracos da solução, bem como as expectativas e necessidades dos usuários. Com os feedbacks, implementar melhorias contínuas na solução, baseadas nos feedbacks recebidos.

**Plano de Oportunidades Reais:**

- **Aplicação de solução nos hospitais:** Buscar parcerias com hospitais que tenham interesse em utilizar a solução. Apresentar os benefícios e vantagens da solução, bem como os requisitos técnicos e operacionais para sua implantação. Fornecer suporte e assistência aos hospitais parceiros.

- **Continuação do MPV pós modulo:** Avaliar o desempenho e os resultados do MPV durante o módulo. Identificar as lições aprendidas e as oportunidades de melhoria. Elaborar um plano de continuidade do MPV, definindo objetivos, metas, indicadores, recursos e cronograma.

- **Diminuição de tempo em triagem:** Medir o tempo médio de triagem dos pacientes e registrar as melhorias obtidas. Gerar relatório comprovando as melhorias observadas.

- **Diminuição do tempo de emergência:** Medir o tempo médio de atendimento dos pacientes na emergência e registrar as reduções de tempo obtidas.Gerar relatório comprovando as melhorias observadas.

- **Redução dos custos:** Medição dos custos pré e pós implementação, a fim de medir com precisão a redução obtida.

&emsp;&emsp;É importante destacar que a matriz de risco é iterativa, o que significa que constantemente ela está sendo alterada, já que riscos deixam de existir por medidas resolutivas tomadas para resolvê-los. Concluindo, com a matriz de risco e as medidas do plano de ação, é possível estruturar uma solução mais segura possível para um modelo de IoT eficiente.

### 3.1.6. Política de Privacidade de acordo com a LGPD

&emsp;&emsp;A Lei Geral de Proteção de Dados⁸ (LGPD) define os direitos do titular dos dados com relação a eles. É regulamentada pela Autoridade Nacional de Proteção de Dados (ANPD) e visa assegurar o uso adequado das informações coletadas. A LGPD abrange a política da privacidade, que é específico sobre como os dados são coletados e usados.(ALBERTACCI, 2021). As informações necessárias para fornecer o serviço dependem do produto ou serviço e é baseado em um contrato,quando exigido por lei, mediante consentimento do cliente.

#### 3.1.6.1 Informações gerais sobre a organização

&emsp;&emsp;Como parceiro de projeto, a Política de Privacidade do Hospital Sírio-Libanês (HSL)⁹ já existente é uma declaração que descreve os tipos de informações coletadas, como elas são usadas, compartilhadas e protegidas. Ao utilizar o website do HSL, o usuário concorda com as práticas descritas na política. E por a solução do projeto Jinwar ser uma extensão dessa organização, está LGPD se baseia nesta organização.

#### 3.1.6.2 Informações sobre o tratamento de dados

&emsp;&emsp;O Hospital Sírio-Libanês (HSL) assegura que o tratamento de dados pessoais é conduzido em estrita conformidade com as leis de proteção de dados aplicáveis, com ênfase na Lei Geral de Proteção de Dados Pessoais (LGPD). O tratamento de dados no HSL engloba a coleta de informações pessoais fornecidas ativamente pelos usuários, como nome completo, e-mail e número de telefone, baseado no consentimento explícito dos mesmos. Além disso, o HSL utiliza medidas técnicas e organizacionais para garantir a segurança dos dados, incluindo proteção contra acesso não autorizado, uso indevido e violações de dados. Embora o HSL se comprometa a manter a privacidade dos usuários, a natureza da internet implica que a segurança total não pode ser garantida, mas o HSL está preparado para agir prontamente em casos de incidentes de segurança.

&emsp;&emsp;Assim sendo o tratamento de dados, o HSL visa oferecer uma experiência respeitosa para os usuários, garantindo que suas informações sejam tratadas com cuidado e em estrita conformidade com as regulamentações de proteção de dados. O consentimento do usuário é fundamental para o tratamento de dados, e o HSL está comprometido em manter a transparência e a segurança em todas as etapas do processo.

#### 3.1.6.3 Quais são os dados coletados

&emsp;&emsp;Segundo a política de proteção de dados da Alma Sírio-Libanês para projeto Jinwar, os seguintes dados são coletados:
Dados pessoais: nome completo, e-mail, número de telefone/celular.
Dados de uso: características do dispositivo de acesso, do navegador, IP (com data e hora), origem do IP, informações sobre cliques, páginas acessadas, as páginas seguintes acessadas após a saída das páginas, ou qualquer termo de procura digitado nos sites ou em referência a estes, dentre outros.

#### 3.1.6.4 Onde os dados são coletados

&emsp;&emsp;Os dados são coletados por meio de cookies, pixeltags, beacons e local shared objects. Essas tecnologias aprimoram a experiência de navegação, adaptando o site às preferências do usuário. Você pode desativar a coleta automática de informações ajustando as configurações do navegador de internet, mas alguns recursos do site podem não funcionar corretamente sem esses dados.

#### 3.1.6.5 Para quais finalidades os dados serão utilizadas

&emsp;&emsp;O Hospital Sírio-Libanês(HSL) utiliza informações e dados pessoais para personalizar o site de acordo com as preferências do usuário e para uso em material institucional, newsletters, convites para palestras e eventos, mediante consentimento do usuário.

#### 3.1.6.6 Onde os dados ficam armazenados

&emsp;&emsp;O Hospital Sírio-Libanês (HSL) adota medidas rigorosas para garantir a segurança dos dados coletados. Os dados são armazenados em um ambiente operacional altamente seguro, com acesso restrito e sem disponibilidade pública. Além disso, o HSL faz uso de tecnologias e infraestrutura de armazenamento de dados em nuvem para a gestão e proteção dessas informações.

#### 3.1.6.7 Qual o período de armazenamento dos dados (retenção)

&emsp;&emsp;O HSL manterá os dados pessoais pelo tempo necessário para cumprir as finalidades para as quais foram coletados, incluindo obrigações legais, contratuais, de prestação de contas ou requisições de autoridades competentes. Quando os dados não forem mais necessários ou relevantes, ou se houver obrigações legais de retenção, eles serão excluídos.

#### 3.1.6.8 Uso de cookies e/ou tecnologias semelhantes

Os cookies são pequenos arquivos de texto que contêm informações como o nome do site que os originou, sua duração e um valor associado. Neste contexto, é importante compreender como o uso de cookies se encaixa nas diretrizes de privacidade e proteção dos dados pessoais dos usuários, por isso, veja a seguir os cookies necessários, funcionais e para marketing, sendo eles acompanhados de descrição e explicitação de quais são utilizados.

- Cookies Necessários: ajudam a entender como os visitantes interagem com as páginas, fornecendo informações sobre as áreas visitadas, o tempo de visita ao site e quaisquer problemas encontrados, como mensagens de erro;

- Espécies: \_ga, \_gid, \_BEAMER_BOOSTED_ANNOUNCEMENT_DATE, \_BEAMER_DATE, \_BEAMER_FIRST_VISIT, \_BEAMER_LAST_POST_SHOWN, \_BEAMER_LAST_UPDATE, \_BEAMER_USER_ID;

- Cookies Funcionais: permitem que as Páginas se lembrem de suas escolhas, para proporcionar uma experiência mais personalizada. Também, possibilitam que os Usuários assistam a vídeos e utilizem ferramentas sociais, campos para comentários, fóruns, entre outros;

- Espécies: \_hjIncludedInPageviewSample, \_hjSessionRejected, \_hjTLDTest, \_hjid, acceptAsPrivacyPolicies;

- Cookies de Marketing: são utilizados para fornecer mais conteúdo relevante e do interesse dos Usuários. Podem ser utilizados para apresentar publicidade mais direcionada ou limitar o número que esta é veiculada nas Páginas. Ainda, esses cookies podem ser utilizados para indicar às Páginas, os sites que o Usuário visitou e o Sírio-Libanês pode compartilhar estas informações com terceiros;

- Espécies: AID, ANID, CONSENT, NID, **Secure-3PAPISID, **Secure-3PSID, DSID, IDE, RUL, 1P_JAR.

#### 3.1.6.9 Com quem esses dados são compartilhados (parceiros, fornecedores, subcontratados)

&emsp;&emsp;Os dados coletados e processados serão compartilhados com a equipe do Alma Sírio-Libanês e com a equipe assistencial do local (usuários finais). Ademais, as informações coletadas podem ser compartilhadas com:
i) Empresas parceiras, quando necessário para a prestação adequada de serviços.
ii) Para proteger os interesses do HSL em conflitos.
iii) Em conformidade com decisões judiciais ou solicitações de autoridades competentes.
Além disso, suas informações podem ser compartilhadas com parceiros específicos contratados, como provedores de infraestrutura tecnológica e serviços de armazenamento em nuvem. Atualmente, compartilha-se dados com os seguintes parceiros:

- Google (Google Analytics e Firebase) - Para obter informações estatísticas sobre o uso dos nossos websites.
- Tasy - Para a gestão de dados de saúde.
- Healthshare - Para armazenamento e gestão de dados e consentimento.
- Carestream - Para armazenamento de exames de imagem e laudos.
- Laboratórios Fleury - Para armazenamento de exames de imagem e laudos.

#### 3.1.6.10 Informações sobre medidas de segurança adotadas pela empresa

&emsp;&emsp; O HSL implementa medidas técnicas e organizacionais para proteger informações e dados pessoais. As informações são armazenadas em um ambiente seguro, inacessível ao público.

#### 3.1.6.11 Orientações sobre como a empresa/organização atende aos direitos dos usuários

&emsp;&emsp; A empresa atende aos direitos dos usuários ao cumprir a regulamentação a respeito de proteção de dados pessoais, por meio das seguintes ações:

1. A confirmação da existência de tratamento;
2. O acesso aos dados;
3. A correção de dados incompletos, inexatos ou desatualizados;
4. A anonimização, bloqueio ou eliminação de dados desnecessários, excessivos ou tratados em desconformidade;
5. A portabilidade de seus dados a outro fornecedor de serviço ou produto, mediante requisição expressa pelo Usuário;
6. A eliminação dos dados tratados com consentimento do Usuário;
7. A obtenção de informações sobre as entidades públicas ou privadas com as quais o HSL compartilhou seus dados;
8. A informação sobre a possibilidade de não fornecer o seu consentimento, bem como de ser informado sobre as consequências, em caso de negativa;
9. A revogação do consentimento.

#### 3.1.6.12 Informações sobre como o titular de dados pode solicitar e exercer os seus direitos

&emsp;&emsp;O titular dos dados pode exercer seus direitos e solicitar seus dados ao agente de tratamento por meio do e-mail dpo.hsl@lbca.com.br, do telefone e do endereço físico em São Paulo.

#### 3.1.6.13 Informações de contato do Data Protection Officer (DPO) ou encarregado de proteção de dados da organização

Agente de tratamento<br>
Hospital Sírio-Libanês - Sociedade Beneficente de Senhoras Hospital Sírio Libanês<br>
CNPJ 61.590.410/0001-24<br>
Rua Adma Jafet, 91, Bela Vista, São Paulo/SP<br>
+55 (11) 3394-0200

### 3.1.7. Bill of Material (BOM)

Antes da montagem e configuração do projeto IoT, é fundamental garantir que todos os componentes necessários estejam disponíveis. A seguir, uma lista detalhada dos materiais que serão usados, a chamada \*Bill od Material(BOM). Esta lista foi cuidadosamente elaborada para garantir que todas as especificidades do projeto sejam atendidas:

<div align="center">
  <p><b>Tabela 01 </b> - Bill of Material</p>
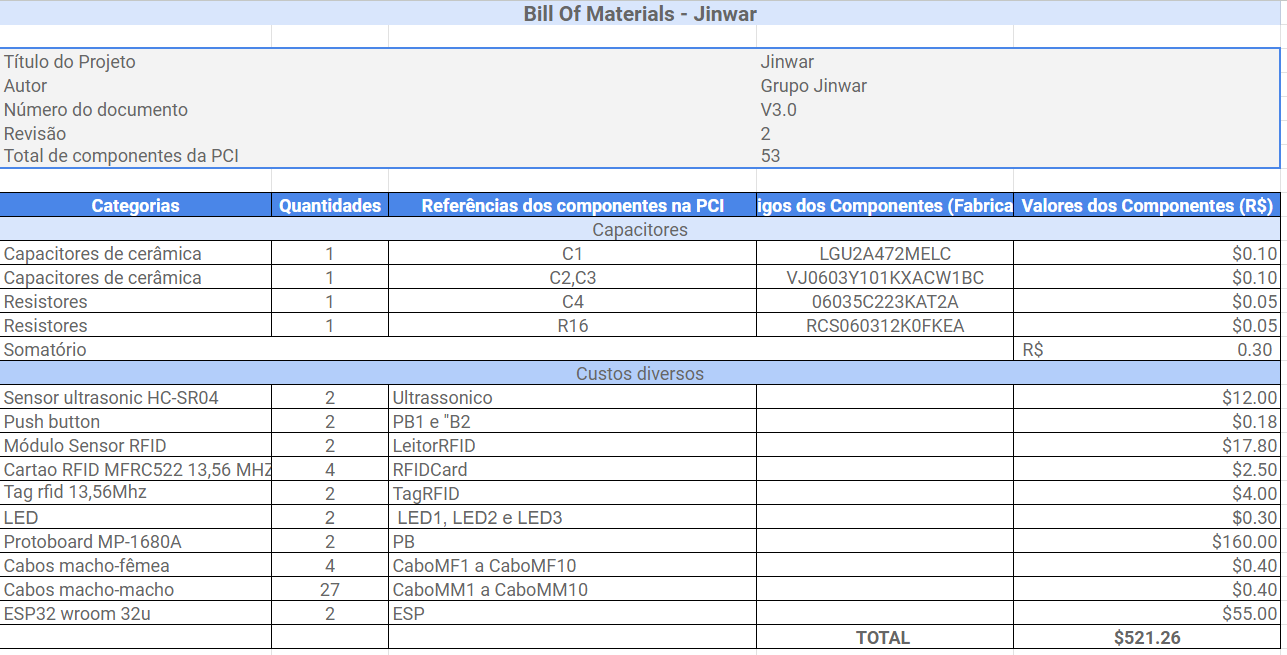
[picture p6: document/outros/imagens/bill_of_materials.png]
  
  <p><b>Fonte:</b> elaboração por Jinwar.</p>
</div>

&emsp;&emsp; A partir do BOM, é possível perceber que as peças de maior valor são a Protoboard MP-1680A, essencial para o planejamento e fácil remontagem do protótipo e a placa ESP32 Wroom 32u, peça central que conecta todas as demais peças e carrega o código, de fato, o código.

## 3.2. Domínio de Fundamentos de Experiência de Usuário

&emsp;&emsp;Nesta seção, busca-se entender quais são as personas do projeto a ser desenvolvido, a jornada de usuário, visualizar storyboards, user stories e desenhos esquemáticos da solução IoT. Dessa maneira, a solução Jinwar poderá ser mais personalizada para os pacientes e colaboradores do Hospital Sírio-Libanês e consequentemente a chance de os usuários adotarem a solução pode ser maior.

### 3.2.1. Personas

&emsp;&emsp;No desenvolvimento de sistemas e soluções, é fundamental entender para qual público se está desenvolvendo. Neste sentido, as personas representam uma ferramenta poderosa para o design centrado no usuário, possibilitando uma visão mais humanizada e próxima da realidade dos futuros usuários. No sprint 1, foram definidas três personas¹¹ principais que irão interagir com o sistema ou produto que será desenvolvido: a paciente, profissional da saúde e o Gestor de Relacionamento Médico-Paciente.

&emsp;&emsp;Conforme destacado no artigo intitulado "Persona Preparedness: A Survey Instrument for Measuring Organizational Readiness for Persona Deployment"¹⁰, as personas desempenham um papel fundamental na promoção da coesão e da clareza de comunicação em equipes de design. Além disso, elas contribuem para elevar o nível de empatia em relação aos usuários, bem como para evitar o viés centrado no desenvolvimento e design de produtos. Devido a esses inúmeros benefícios, a criação de personas se torna uma ferramenta essencial para obter uma compreensão holística do projeto Iot. Veja a seguir a construção das persona da equipe Jinwar.

&emsp;&emsp;A paciente, Maria dos Santos, é uma mulher de meia-idade que busca uma experiência hospitalar humanizada, eficiente e que respeite suas necessidades enquanto indivíduo. Sua vida agitada em São Paulo e sua família são centrais em suas decisões, e sua interação com a saúde digital revela um perfil intermediário no que tange ao letramento digital.

&emsp;&emsp;Por outro lado, temos o profissional da saúde, Dr. Roberto Oliveira, um cardiologista experiente que valoriza a otimização do tempo, a formação contínua e as tecnologias de ponta para proporcionar o melhor atendimento possível aos seus pacientes. Seu letramento digital é avançado, demonstrando a necessidade de um sistema que atenda suas demandas de maneira eficiente.

&emsp;&emsp;Adicionalmente, introduzimos uma terceira figura chave no cenário de interações do nosso sistema: Rafael Souza, ocupando o essencial papel de Gestor de Relacionamento Médico-Paciente. Sua inclusão na lista de personas é estratégica e visa aprimorar a compreensão das dinâmicas internas e externas do ambiente hospitalar, garantindo assim a conexão entre o paciente e o profissional da saúde.

&emsp;&emsp;Ao detalharmos estas personas, é possível entender melhor suas dores, desejos e necessidades, permitindo o desenvolvimento de soluções mais alinhadas com suas expectativas e realidades. A seguir, um aprofundamento em cada uma dessas personas para compreender mais sobre seus backgrounds e como elas interagem com o produto.

#### **Persona: Paciente**

<div align="center">
  <p><b>Figura 05 </b> - Persona 1 </p>
  
  <p><b>Fonte:</b> elaboração por Jinwar com uso de IA this-person-does-not-exist.</p>
</div>

**Nome:** Maria dos Santos

**Informações demográficas:**

- **Idade:** 45 anos
- **Estado Civil:** Casada
- **Filhos:** Dois adolescentes
- **Profissão:** Professora em uma escola local
- **Localização geográfica:** São Paulo, SP
- **Perfil socioeconômico:** Classe média
- **Formação acadêmica:** Graduação em Pedagogia

&emsp;&emsp; **Background:** Maria é uma dedicada professora que equilibra sua carreira com o cuidado de seus dois filhos adolescentes. Moradora da cidade de São Paulo, ela vive um cotidiano agitado entre trabalho, casa e compromissos pessoais. Tem uma vida ativa e valoriza muito a saúde, tanto a sua quanto a de sua família.

**Dores, necessidades e desejos:**

1. Desejo de ser atendida rapidamente.
2. Precisa de uma experiência de atendimento eficiente, evitando esperas prolongadas entre procedimentos.
3. Valoriza a humanização no atendimento, sentindo-se mais tranquila quando os profissionais têm conhecimento sobre sua saúde e histórico.
4. Acredita na importância do envolvimento do paciente e da família no processo de cuidado.
5. Espera que o hospital tenha coordenação no cuidado para evitar uso desnecessário de recursos.

&emsp;&emsp; **Cenários de interação:** Maria costuma ir ao hospital para exames de rotina e consultas médicas. Ela interage com o sistema e produtos tanto na sala de espera quanto durante seus procedimentos médicos.

**Interesses e hábitos relacionados ao sistema ou produto:**

- Frequentemente lê sobre saúde e bem-estar para se manter informada.
- Usa aplicativos de saúde no celular para monitorar sua diabetes.
- Pesquisa sobre inovações na área de saúde, como a computação ubíqua, para entender como podem auxiliá-la em seu tratamento.

**Nível de letramento digital:**

&emsp;&emsp;Intermediário. Maria utiliza tecnologias diariamente, tanto para o trabalho quanto para assuntos pessoais. No entanto, pode ter dificuldades com tecnologias muito avançadas ou interfaces complicadas.

**Citações diretas:**

- "Eu preciso saber que estão cuidando de mim e que conhecem meu histórico."
- "A saúde não é só física, é preciso humanizar o atendimento."
- "Meus filhos e eu somos uma equipe. Todos nós temos um papel no cuidado da minha saúde."

---

#### **Persona: Profissional da saúde¹²**

<div align="center">
  <p><b>Figura 06 </b> - Persona 2 </p>
  
  <p><b>Fonte:</b> elaboração por Jinwar com uso de IA this-person-does-not-exist.</p>
</div>

**Nome:** Dr. Roberto Oliveira

**Informações demográficas:**

- **Idade:** 38 anos
- **Especialidade:** Cardiologia
- **Estado Civil:** Solteiro
- **Hobbies:** Correr em parques
- **Localização no hospital:** Consultório
- **Anos de experiência:** 10 anos

&emsp;&emsp; **Background:** Dr. Roberto Oliveira é um cardiologista com 10 anos de experiência e atualmente trabalha no Hospital Sírio-Libanês. Em seu tempo livre, gosta de correr em parques.

**Dores, necessidades e desejos:**

1. Otimização de tempo entre os pacientes, garantindo cuidado adequado.
2. Acesso rápido a informações sobre o local de seus pacientes e outros membros da equipe.
3. Valorização da formação contínua e oportunidade de compartilhar conhecimentos com profissionais renomados da saúde.
4. Apreciação pela tecnologia de ponta do hospital, visando a melhoria na eficiência e precisão na entrada de dados.

**Cenários de interação:¹³** Dr. Roberto passa grande parte de seu tempo no consultório, mas frequentemente visita a UTI Cardiológica e a Sala de Exames.

**Interesses e hábitos relacionados ao sistema ou produto¹⁴:**

- Está sempre em busca de formação contínua e atualizações na área de cardiologia.
- Usa sistemas digitais de saúde para gerenciar prontuários e agendar consultas.
- Valoriza a troca de conhecimento com colegas da área e participa ativamente de conferências e seminários.

**Nível de letramento digital:**

&emsp;&emsp; Avançado. Dr. Roberto é fluente em várias tecnologias e sistemas de saúde, e sente-se confortável em adaptar-se a novas plataformas conforme necessário.

**Citações diretas:¹⁵**

- "Preciso otimizar meu tempo entre pacientes para garantir um atendimento de qualidade."
- "A formação contínua e a troca de conhecimento são fundamentais na medicina."
- "A tecnologia de ponta do hospital é essencial para minha prática médica diária."

---

#### **Persona: Gestor de Relacionamento Médico-Paciente**

<div align="center">
  <p><b>Figura 07 </b> - Persona 3 </b></p>
  
  <p><b>Fonte:</b> elaboração por Jinwar com uso de IA this-person-does-not-exist.</p>
</div>

**Nome:** Rafael Souza

**Informações demográficas:**

- **Idade:** 35 anos
- **Especialidade:** Gestão em Saúde
- **Estado Civil:** Casado
- **Filhos:** 1 filho de 6 anos
- **Profissão:** Gestor de Relacionamento Médico-Paciente
- **Localização geográfica:** São Paulo, SP
- **Perfil socioeconômico:** Classe média-alta
- **Formação acadêmica:** MBA em Gestão Hospitalar

&emsp;&emsp; **Background:¹⁶** Rafael trabalha há 8 anos no Hospital Sírio-Libanês, coordenando a ligação entre médicos de alto padrão, como Dr. Roberto Oliveira, e pacientes afluentes que frequentam o hospital em busca do melhor cuidado médico. Ele entende as demandas e particularidades desse público, garantindo que a comunicação entre o médico e o paciente ocorra de forma eficaz e personalizada.

**Dores, necessidades e desejos:**

1. Assegurar que as necessidades específicas dos pacientes sejam atendidas com excelência.
2. Facilitar a comunicação entre médicos e pacientes, otimizando o tempo de ambos.
3. Mantém um alto padrão de atendimento, refletindo a reputação de elite do hospital.
4. Busca continuamente feedbacks para melhorar a experiência do paciente.
5. Precisa lidar com as expectativas elevadas de pacientes que buscam um serviço diferenciado.

**Cenários de interação:¹⁷** Rafael divide seu tempo entre o escritório, salas de reunião, e acompanhamento da interação entre médicos e pacientes em áreas como a UTI Cardiológica, Sala de Exames, consultórios e Pronto Atendimento.

**Interesses e hábitos relacionados ao sistema ou produto:**

- Em constante contato com novas tecnologias que podem melhorar o relacionamento médico-paciente.
- Participa de treinamentos e workshops para aprimorar suas habilidades em gestão de relacionamento.
- Focado em criar um ambiente harmonioso e eficaz para médicos e pacientes.

**Nível de letramento digital:**

&emsp;&emsp;Avançado. Rafael está acostumado a trabalhar com sistemas digitais de saúde e plataformas de CRM (Customer Relationship Management).

**Citações diretas:**

- "A comunicação eficaz entre médico e paciente é crucial para manter o padrão Sírio-Libanês."
- "Entender as nuances e expectativas de nossos pacientes é fundamental, não importa se ele(a) seja influente ou não."
- "Precisamos estar sempre um passo à frente, oferecendo soluções inovadoras para aprimorar a experiência do paciente."

---

&emsp;&emsp;Conclui-se que a elaboração de personas, como Maria dos Santos, Dr. Roberto Oliveira e Rafael Souza oferecem perspectivas sobre a realidade diversa e multifacetada dos potenciais usuários de um sistema ou produto. Estas personas emergem como ferramentas inestimáveis que orientam equipes de design e desenvolvimento, permitindo-lhes abordar com maior precisão as necessidades autênticas dos usuários.

&emsp;&emsp;Ao aprofundar na compreensão destas personas e ao integrar os insights do design centrado no usuário, é possível assegurar que as soluções criadas sejam não apenas avançadas do ponto de vista tecnológico, mas também profundamente relevantes em termos humanos. No entrelaço entre tecnologia e humanidade, há o genuíno potencial para transformação e inovação no campo da saúde.

### 3.2.2. Jornadas do Usuário e Storyboard

&emsp;&emsp;Um Canvas de **Jornada do Usuário**¹⁸ é uma ferramenta visual que permite mapear de forma concisa a experiência do usuário ao interagir com um produto, neste caso, a solução Jinwar. Além disso, pode-se encontrar os passos das personas relacionados à solução em questão, destacando suas ações, sentimentos, pensamentos e planejamentos ao longo de sua jornada. Essa ferramenta desempenha um papel crucial no design centrado no usuário, pois fornece uma representação abrangente das interações do usuário com o produto, permitindo às equipes identificar pontos de dor, oportunidades de melhoria e criar soluções mais alinhadas às necessidades e expectativas dos usuários, como por exemplo, para um paciente, ser atendido rápido; e para um médico, identificar rapidamente para onde deve ir . Ademais, o Canvas de Jornada do Usuário promove uma compreensão compartilhada do cliente em toda a equipe, facilitando uma abordagem mais eficaz no desenvolvimento, resultando em experiências mais satisfatórias. Veja a seguir as jornadas de usuário das personas Maria dos Santos e Dr. Roberto Oliveira.

<div align="center">
  <p><b>Figura 08</b> - Jornada do Usuário 1</p>
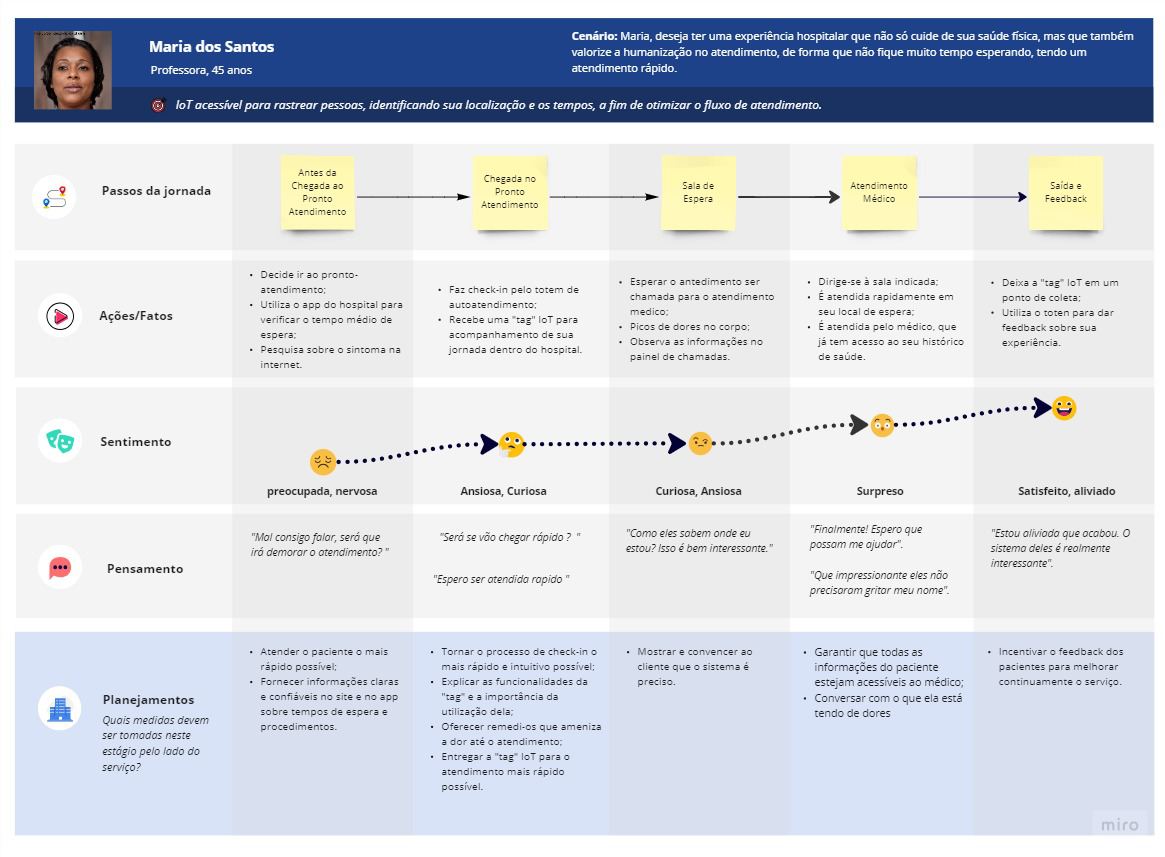
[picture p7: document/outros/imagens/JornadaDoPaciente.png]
Jornada do Usuário1
  
  <p><b>Fonte:</b> elaboração por Jinwar.</p>
</div>

<div align="center">
  <p><b>Figura 09</b> - Jornada do Usuário 2</p>
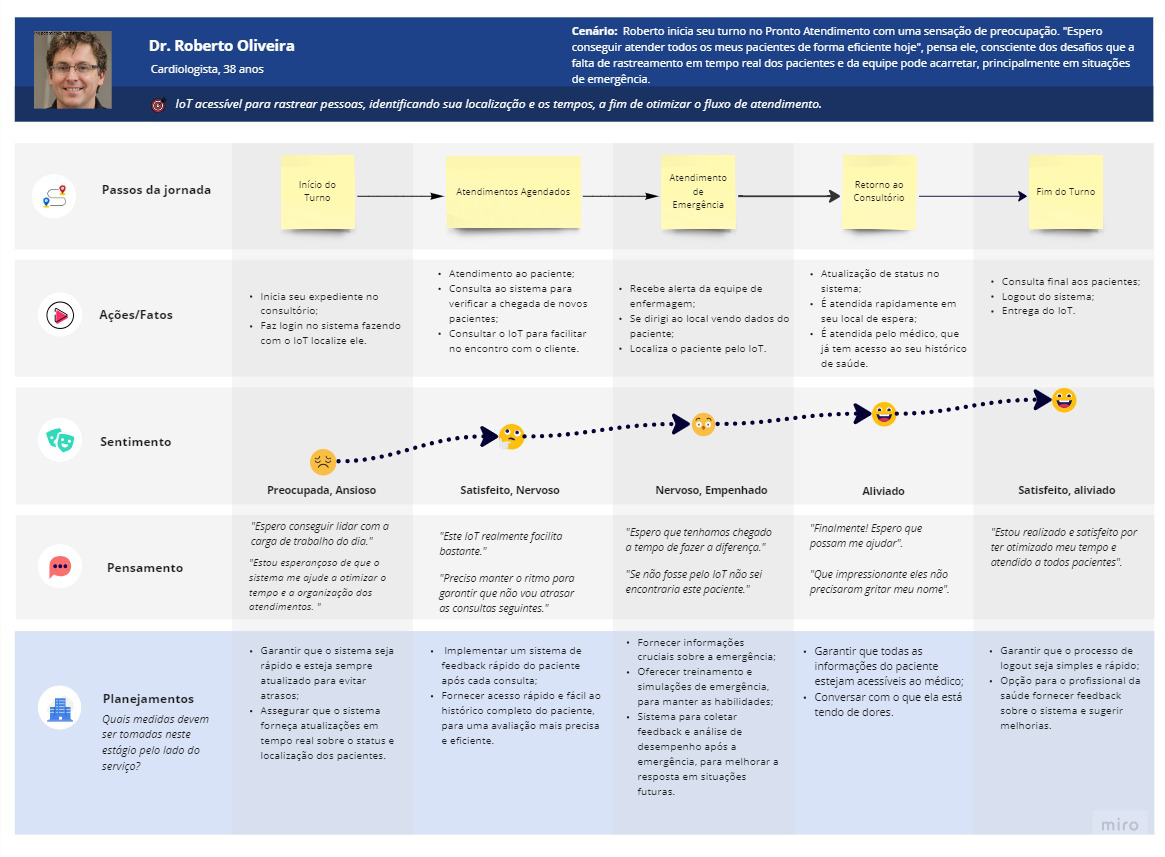
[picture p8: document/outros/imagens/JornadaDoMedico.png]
Jornada do Usuário2
  
  <p><b>Fonte:</b> elaboração por Jinwar.</p>
</div>

&emsp;&emsp;Dessa forma, a jornada do usuário proporciona uma visão detalhada das etapas cruciais para as personas, como a urgência do tratamento do paciente no contexto hospitalar, minimizando a perda de tempo na triagem para garantir sua saúde e bem-estar. Além disso, ela delineia a importância da coleta de feedback para aprimorar a solução. No que tange ao médico, a jornada descreve a entrada e saída no sistema, potencialmente simplificada por meio de um check-out automático, além de considerar a criação de um painel de orientação para o médico. Essa abordagem também abre portas para a expansão do escopo, incluindo o desenvolvimento de uma interface que permita uma rápida visualização dos dados do paciente já cadastrado, beneficiando o atendimento do sistema no caso da continuação do MVP( Produto Mínimo Viável).

&emsp;&emsp;Um **storyboard**¹⁹ é uma ferramenta visual que descreve uma narrativa de eventos por meio de uma série de ilustrações organizadas em um painel ou quadro. No contexto da solução IoT, o storyboard é uma representação gráfica que detalha a interação entre dispositivos, sistemas e usuários, demonstrando como a tecnologia IoT é usada para resolver um problema ou atender a uma necessidade específica.

&emsp;&emsp;Ele desempenha um papel crucial, pois permite que os designers, engenheiros e stakeholders visualizem a implementação da tecnologia em ação. Além disso, um storyboard pode destacar os pontos de dor ou oportunidades de melhoria no processo, facilitando a identificação de aprimoramentos antes da implementação real da solução IoT. Veja a seguir o Storyboard do projeto:

<div align="center">
  <p><b>Figura 10</b>- Storyboard </b></p>
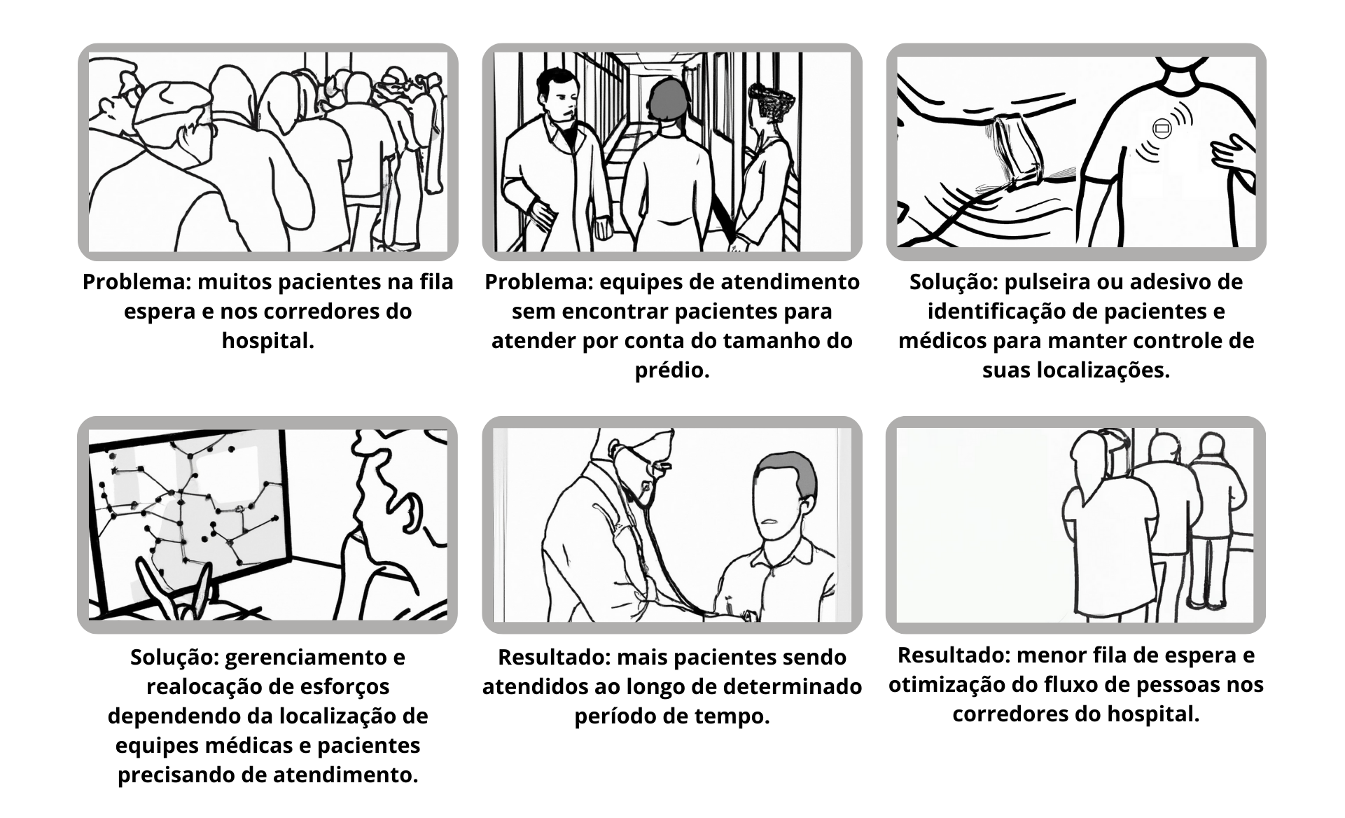
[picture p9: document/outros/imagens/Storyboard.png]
Storyboard
  
  <p>Fonte: elaboração por Jinwar e uso da plataforma DALL·E 2 para geração das imagens.</p>
</div>

&emsp;&emsp;Como demonstrado no storyboard, o objetivo da solução IoT é minimizar as dificuldades enfrentadas tanto pelos pacientes na espera quanto pelos funcionários do hospital no fluxo de trabalho. Isso se torna possível através da otimização do trânsito e atendimento no hospital, por meio da identificação da localização de pacientes e médicos, e, posteriormente, pela realocação eficaz de recursos, de acordo com a disponibilidade de equipes de atendimento em tempo real.

### 3.2.3. User Stories

&emsp;&emsp;No desenvolvimento de projetos, compreender as necessidades de todos os envolvidos é de suma importância. As User Stories são instrumentos valiosos neste contexto, pois permitem capturar requisitos sob a ótica do usuário final de maneira clara e direta.

&emsp;&emsp;De acordo com Ricardo Arruda no artigo “o que são User Stories(Estórias de Usuário)”²⁰, uma **User Story** é a representação clara e informal que expressa a necessidade e/ou requisito de um potencial usuário. Também pode ser considerada uma parte de um objetivo final. A User Story é a menor unidade de trabalho com base na “necessidade do cliente final que vai utilizar e/ou interagir com o Produto.”

&emsp;&emsp;Uma User Story é uma breve descrição de uma necessidade ou desejo do usuário, redigida a partir de sua perspectiva. Elas não apenas destacam funcionalidades baseadas nas demandas reais dos stakeholders, mas também direcionam o desenvolvimento para o que é verdadeiramente crucial: entregar valor ao usuário.

&emsp;&emsp;Por meio das User Stories, conseguimos identificar e priorizar funcionalidades, estabelecer critérios de aceitação e assegurar que o sistema desenvolvido esteja em sintonia com as necessidades autênticas dos usuários. Além disso, essas histórias conferem uma visão mais clara sobre o MVP (Produto Mínimo Viável) que será entregue ao cliente, ajudando a dissipar quaisquer dúvidas sobre os desafios específicos que o projeto visa abordar. Para maximizar sua eficácia, é essencial que todos os stakeholders, como pacientes, equipe médica, gerentes, entre outros, estejam envolvidos no processo de definição e documentação dessas histórias.

&emsp;&emsp;Para exemplificar como as User Stories podem abordar essas necessidades no contexto hospitalar, eis algumas histórias:

- Como paciente do PA, desejo ser rapidamente encaminhado para a triagem logo após minha chegada, para que eu possa ter minha situação prontamente avaliada e, consequentemente, retornar para minha rotina e família o mais breve possível.

- Como paciente em consulta, é de meu interesse ser direcionado de maneira clara e eficiente logo após o término da mesma, para que eu possa, conforme a recomendação médica, seguir para a enfermaria ou sala de emergência sem enfrentar confusões, ou demoras desnecessárias.

- Como médico(a) atuante no PA, é vital para mim contar com um processo de triagem eficiente para que eu otimize meu atendimento, possibilitando que eu me concentre integralmente nas necessidades mais urgentes dos pacientes que buscam auxílio.

- Como atendente da recepção do PA, anseio por uma ferramenta ou método eficaz de gerenciamento de filas, para que eu possa categorizar, organizar e priorizar os pacientes conforme suas necessidades individuais, garantindo, assim, um atendimento ágil e humanizado.

- No contexto de uma emergência, como médico(a), preciso ter acesso a informações claras e atualizadas sobre o status e localização do paciente em crise. A agilidade e precisão dessas informações são vitais para que decisões rápidas sejam tomadas, maximizando as chances de um desfecho positivo.

- Como gerente de operações hospitalares, eu quero relatórios detalhados sobre o tempo que pacientes e equipe gastam em diferentes estágios do fluxo do PA, para que eu possa identificar gargalos e otimizar os processos internos, melhorando a qualidade e eficiência do atendimento.

&emsp;&emsp;Diante disso, a incorporação de User Stories provou ser um método eficaz para capturar e priorizar as necessidades dos usuários finais, alinhando as soluções propostas com as demandas reais dos stakeholders envolvidos no contexto hospitalar. Através de uma comunicação clara e direta, foi possível desenhar funcionalidades que não apenas atendem às expectativas dos usuários, mas também proporcionam uma entrega de valor significativa, visando a otimização de processos e a melhoria contínua na prestação de serviços hospitalares.

&emsp;&emsp;Este processo reforça a importância de uma abordagem centrada no usuário, especialmente em ambientes críticos como o hospitalar, onde a eficácia do atendimento é de suma importância. A metodologia de User Stories, conforme descrito por Ricardo Arruda, serviu como um instrumento valioso para traduzir as necessidades dos usuários em requisitos funcionais, proporcionando uma base sólida para o desenvolvimento de um sistema que busca atender de maneira eficiente às demandas apresentadas neste contexto específico.

### 3.2.4. Protótipo de interface com o usuário

&emsp;&emsp;Os protótipos de desenvolvidos para uma solução IoT voltada para a identificação hospitalar, tem o objetivo é mostrar como a solução proposta pode facilitar o acesso e o gerenciamento das informações dos pacientes, dos profissionais de saúde e dos ambientes do hospital, por meio de tags adesivas que contêm dados relevantes e que podem ser lidas por dispositivos ESP32 com RFID. Para ilustrar a solução, foi desenvolvido Desenhos Esquemáticos e um Wireframe que ajudam a visualizar a solução e objetificar como será feito o desenvolvimento dela. Vejam a descrição delas mais aprofundadas a seguir. Para maior qualidade de interação, **acesse o link do Figma:** [Protótipo de interface](https://www.figma.com/file/muPUUxIcDjIYIxSHhlDXJ9/wireframe_jin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) com ambas interfaces e guia de estilos da solução.

#### 3.2.4.1 Desenhos Esquemáticos

&emsp;&emsp;Os desenhos esquemáticos desenvolvidos para uma solução IoT Jin do grupo Jinwar é voltada para a identificação hospitalar. O objetivo é mostrar como a solução proposta pode facilitar o acesso e o gerenciamento das informações dos pacientes, dos profissionais de saúde e dos ambientes do hospital, por meio de tags adesivas que contêm dados relevantes e que podem ser lidas por dispositivos ESP32 com RFID.

&emsp;&emsp;Os desenhos esquemáticos são representações gráficas simplificadas da solução IoT, indicando os sensores, controles e atuadores do dispositivo, bem como as possíveis interações e leituras de estado do sistema. Eles permitem visualizar o funcionamento e a arquitetura da solução, sem entrar em detalhes técnicos ou estéticos.

&emsp;&emsp;A seguir, foi descrito os desenhos esquemáticos desenvolvidos, explicando como as tags adesivas podem ser usadas como wearables pelos médicos, fisioterapeutas e outros, e como elas podem ser coladas nos pacientes e nos equipamentos em caso de necessidade. Cada tag possui um chip RFID que transmite os dados por meio de ondas de rádio. Em cada ambiente do hospital, há um ESP32 com RFID que recebe os dados das tags e os envia para um servidor central. O ESP32 é um microcontrolador que permite a configuração, inserção e adaptação dos dados para os clientes e o corpo médico. Assim, o sistema de IoT proporciona uma maior eficiência, segurança e qualidade no atendimento hospitalar.

<div align="center">
  <p><b>Figura 11</b>- Desenho Esquemático 1 </b></p>
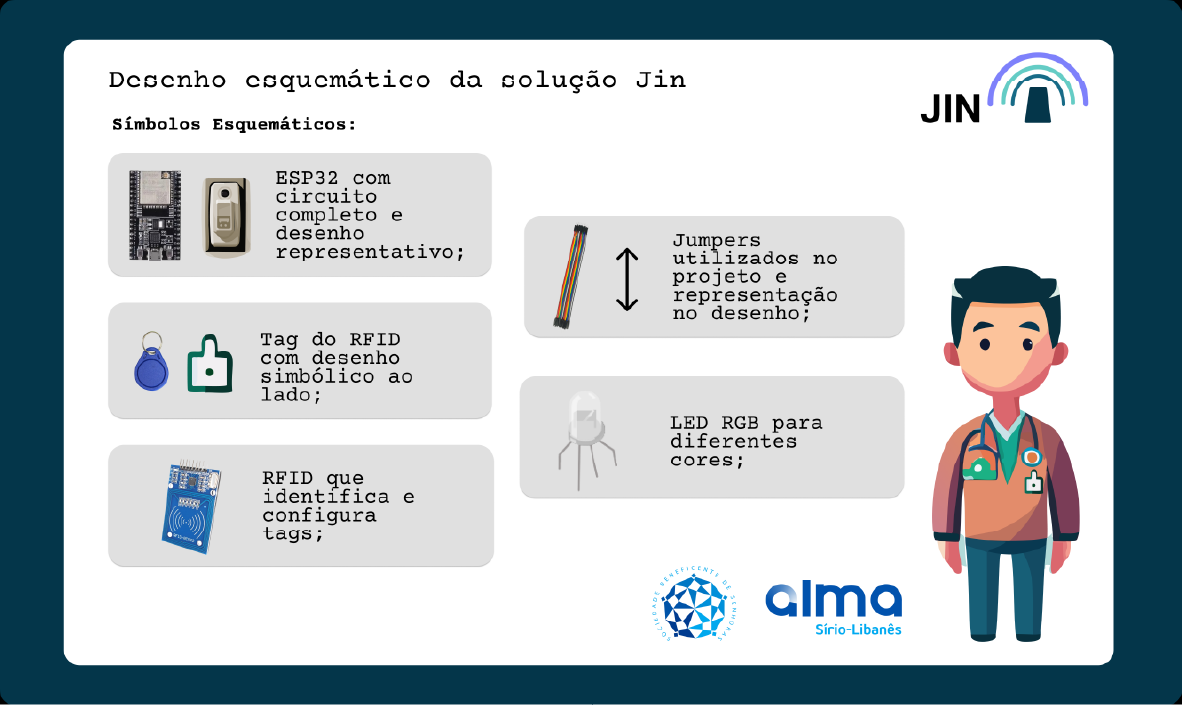
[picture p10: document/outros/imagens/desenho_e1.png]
Desenho Esquemático
  
  <p><b>Fonte:</b> elaboração por Jinwar com uso da Firefly Vector, IA em versão Beta do  Adobe Illustrator.</p>
</div>
<div align="center">
  <p><b>Figura 12</b>- Desenho Esquemático 2 </b></p>
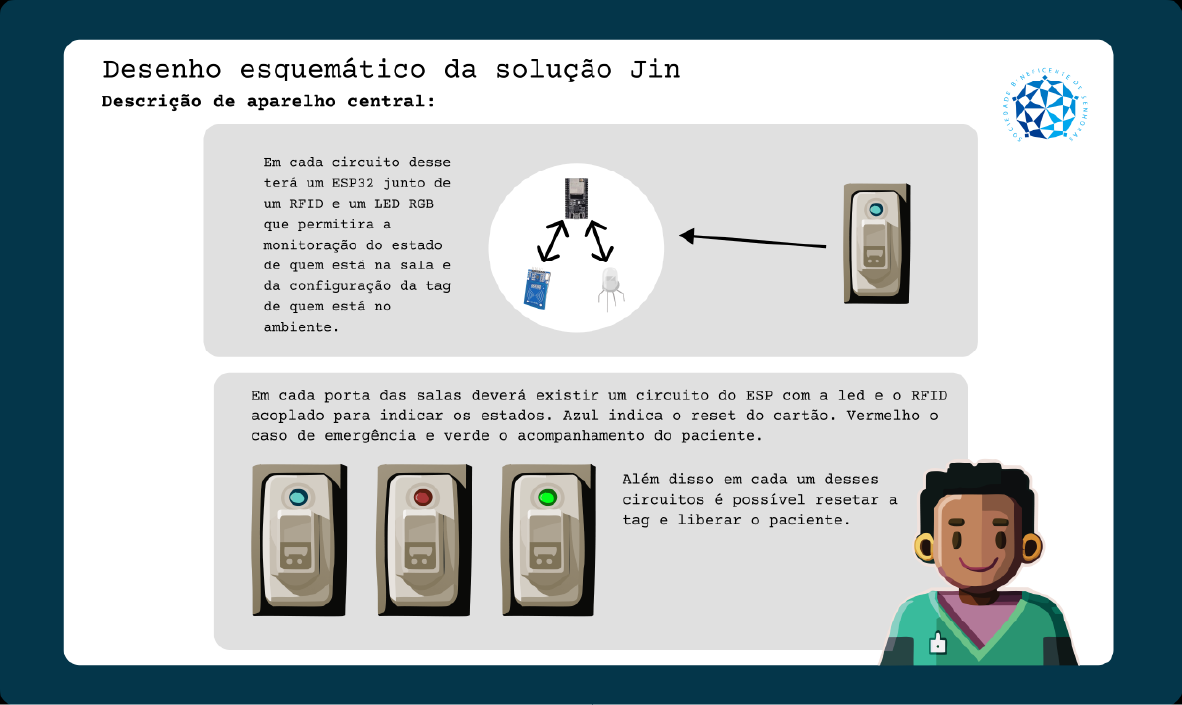
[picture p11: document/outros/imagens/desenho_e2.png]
Desenho Esquemático
  
  <p><b>Fonte:</b> elaboração própria com uso da Firefly Vector, IA em versão Beta do  Adobe Illustrator.</p>
</div>
<div align="center">
  <p><b>Figura 13</b>- Desenho Esquemático 3</b></p>
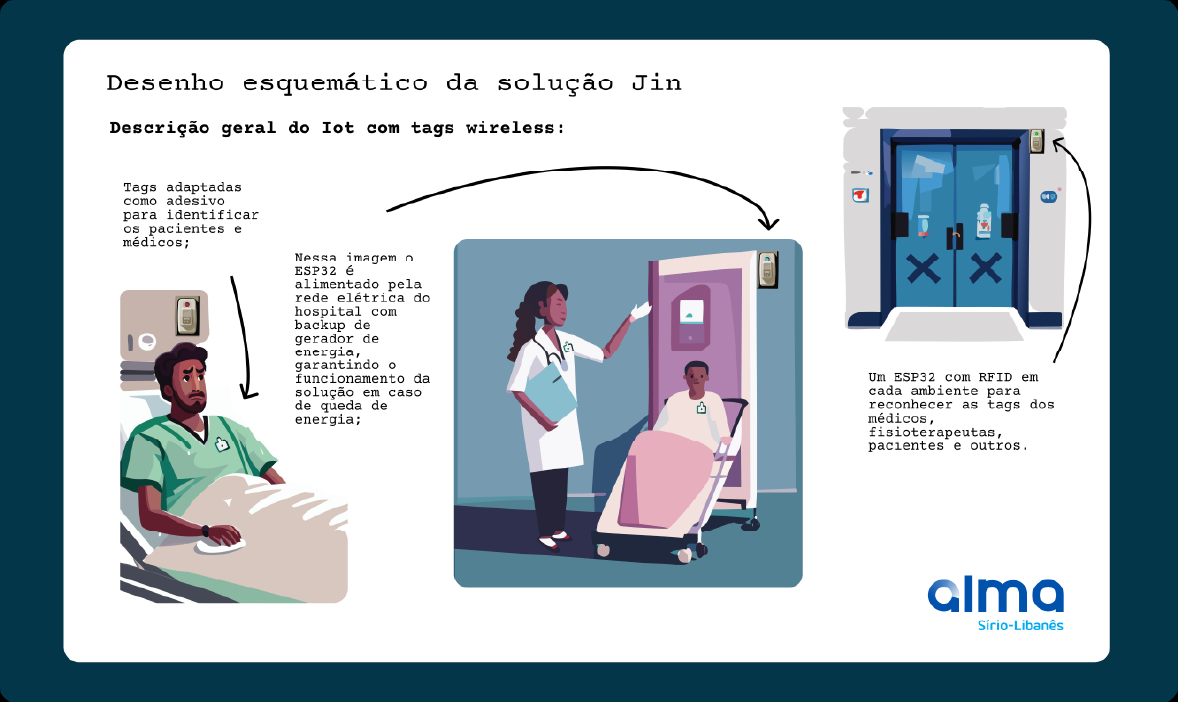
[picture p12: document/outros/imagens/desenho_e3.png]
Desenho Esquemático
  
  <p><b>Fonte:</b> elaboração por Jinwar com uso da Firefly Vector, IA em versão Beta do  Adobe Illustrator.</p>
</div>
<div align="center">
  <p><b>Figura 14</b>- Desenho Esquemático 4 </b></p>
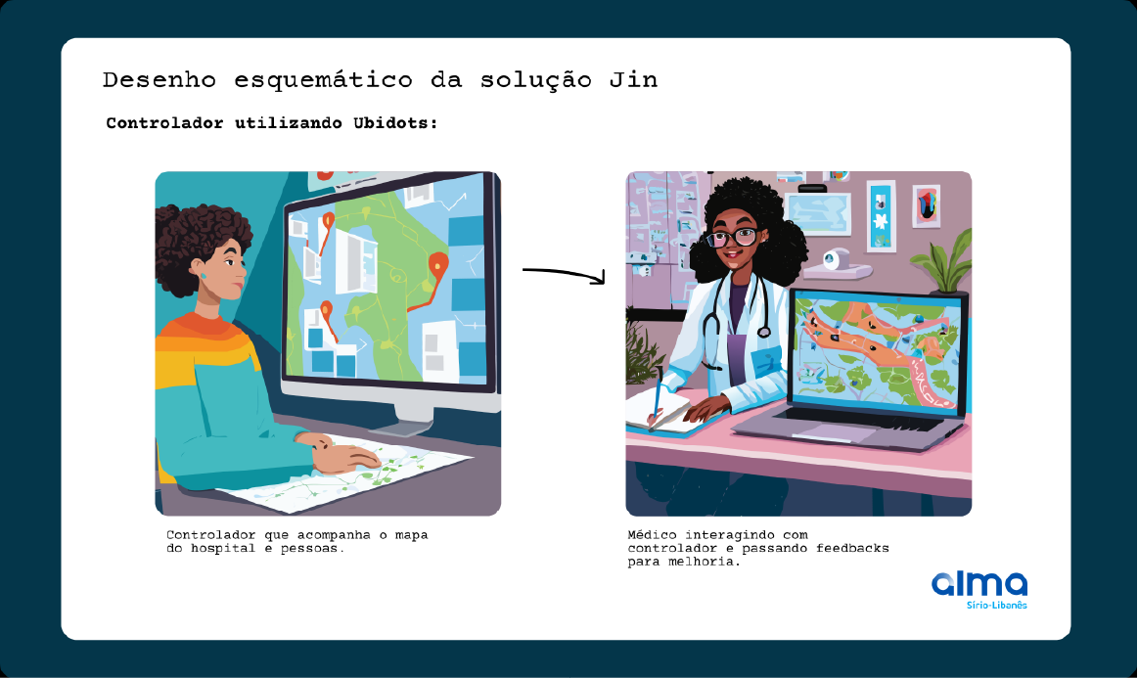
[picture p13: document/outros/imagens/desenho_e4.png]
Desenho Esquemático
  
  <p><b>Fonte:</b> elaboração por Jinwar com uso da Firefly Vector, IA em versão Beta do  Adobe Illustrator.</p>
</div>

&emsp;&emsp; Os desenhos esquemáticos apresentados revelam a funcionalidade das tags adesivas no sistema de IoT para identificação hospitalar. O propósito principal é simplificar o acesso e a gestão das informações dos pacientes, profissionais de saúde e ambientes hospitalares. No entanto, os esquemas não apenas facilitam essa função, mas também auxiliam na detecção de possíveis falhas. Cada figura demonstra a operação da solução; especificamente, a Figura 14 destaca a interação entre o médico e o controlador. O controlador, representado pela mulher à esquerda, está direcionado para o painel de controle, enquanto a médica à direita consulta a localização do paciente a ser atendido. A solução proposta por Jinwar consiste em tags utilizáveis como dispositivos vestíveis por médicos, fisioterapeutas e outros profissionais, contendo dados relevantes sobre o ambiente e as pessoas identificadas. Estas tags podem ser aplicadas nos pacientes e equipamentos conforme necessário, permitindo identificar indivíduos, localizações e atividades. Cada tag é equipada com um chip RFID que transmite dados via ondas de rádio. Em cada ambiente hospitalar, um ESP32 com RFID recebe e encaminha os dados das tags para um servidor central. O ESP32, um microcontrolador versátil, possibilita a configuração, inserção e adaptação dos dados para os clientes e equipe médica. Dessa forma, o sistema de IoT eleva a eficiência, segurança e qualidade do atendimento hospitalar.

&emsp;&emsp;Quando observa-se as jornadas do usuário, as personas estabelecidas, como o Dr. Roberto (médico) e Maria (paciente), terão a oportunidade de economizar tempo significativamente. As Figuras 8 e 9, ilustrando as jornadas do usuário, destacam como a solução pode otimizar o tempo deles e identificar oportunidades para economia de tempo em todo o fluxo do pronto atendimento.

#### 3.2.4.2 Wireframe

&emsp;&emsp;Os wireframes são representações gráficas simplificadas da interface da dashboard, que é a plataforma web onde os dados da solução IoT podem ser acessados e visualizados. Eles permitem visualizar a estrutura e o layout da interface, sem entrar em detalhes de cores, fontes ou imagens. Os wireframes desenvolvidos foram baseados nas possibilidades do sistema Ubidots, que é uma plataforma de IoT que oferece recursos para criar dashboards personalizados. Os wireframes mostram como a dashboard pode exibir as informações dos pacientes, dos profissionais de saúde e dos ambientes do hospital, por meio de gráficos, tabelas, mapas e outros elementos visuais. Veja o wireframe a seguir:

<div align="center">
  <p><b>Figura 15</b>- Dashboard</b></p>
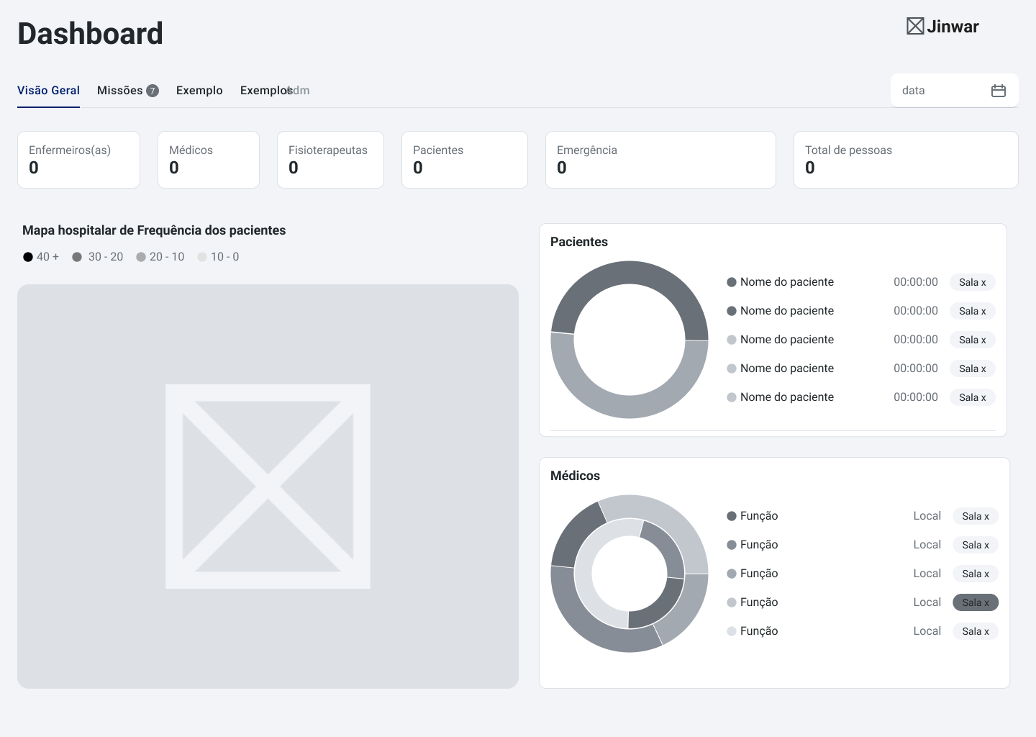
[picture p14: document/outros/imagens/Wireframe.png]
Dashboard
  
  <p><b>Fonte:</b> elaboração por Jinwar.</p>
</div>

&emsp;&emsp;Conclui-se, portanto, que os wireframes são ferramentas indispensáveis na criação de dashboards para soluções em Internet das Coisas (IoT), oferecendo uma representação visual simplificada crucial para o planejamento inicial das interfaces de usuário. Especificamente para uma plataforma web direcionada à gestão do relacionamento médico-paciente na área da saúde, os wireframes facilitam a organização e a exibição das informações de pacientes, profissionais de saúde e do ambiente hospitalar. Utilizando o sistema Ubidots, mencionado anteriormente, é possível desenvolver dashboards personalizados e flexíveis, notáveis pela habilidade de combinar diversos tipos de dados em elementos visuais, como gráficos, tabelas e mapas. Esse dashboard foi desenvolvido para o controlador, referenciado na persona 3 (figura 7), pensando em como as informações poderiam ser mais facilmente compreendidas para auxiliar na organização dos médicos até seus pacientes. Essa abordagem não só aprimora a experiência do controlador, mas também a gestão e o monitoramento de dados vitais no contexto hospitalar, contribuindo assim para um funcionamento mais eficiente e uma tomada de decisão informada.

## 3.3. Solução Técnica

&emsp;&emsp; A solução técnica proposta para atender às demandas de um projeto de Internet das Coisas (IoT) é fundamentada em um conjunto de Requisitos Funcionais. Estes requisitos descrevem as funcionalidades e operações cruciais que um sistema IoT deve desempenhar. Inicialmente, é vital que o sistema seja capaz de identificar o portador da _tag_ e atribuir a ele um papel dentro da instituição, como Paciente, Fisioterapia, Enfermagem ou Médico. Esses requisitos funcionais fornecem uma base sólida para o desenvolvimento do projeto, por isso, veja a seguir as demais seções sobre a solução técnica.

### 3.3.1. Requisitos Funcionais

&emsp;&emsp; Os Requisitos Funcionais são as especificações que descrevem as funções, capacidades e operações que um sistema deve desempenhar em um projeto de Internet das Coisas (IoT). Eles são essenciais para garantir que um dispositivo IoT ou sistema atenda às necessidades e expectativas dos usuários.

&emsp;&emsp; **RF1: Identificação do portador da _Tag_**  
Descrição: O sistema deve ser capaz de identificar o portador da _tag_ e atribuir a ele um papel dentro da instituição, como Paciente, Fisioterapia, Enfermagem ou Médico.

&emsp;&emsp; **Regra de Negócio Relacionada:** O sistema deve utilizar informações precisas para garantir a identificação correta do portador da _tag_ e seu papel, evitando confusões no direcionamento do atendimento.

&emsp;&emsp; **RF2: Rastreamento em tempo real**
Descrição: O sistema deve ser capaz de rastrear a localização do portador da _tag_ em tempo real, enquanto ele se move dentro do hospital.

&emsp;&emsp; **Regra de Negócio Relacionada:** O sistema deve garantir um rastreamento preciso e contínuo, minimizando atrasos e erros de localização.

&emsp;&emsp; **RF3: Avaliação de Tempos de Chegada e Saída**  
Descrição: O sistema deve permitir a avaliação dos tempos de chegada e saída do portador da _tag_ em regiões demarcadas dentro do hospital.

&emsp;&emsp; **Regra de Negócio Relacionada:** As demarcações devem ser definidas de forma precisa, ajudando na identificação de áreas críticas do hospital.

&emsp;&emsp; **RF4: Resposta a Códigos de Emergência**  
Descrição: O sistema deve permitir que o portador da _tag_ possa expressar uma ação em resposta a códigos de emergência e receber informações sobre a localização do código e quais equipes estão respondendo a ele.

&emsp;&emsp; **Regra de Negócio Relacionada:** A comunicação de códigos de emergência e as ações subsequentes devem ser eficazes para garantir a segurança dos pacientes.

&emsp;&emsp; **RF5: Avaliação de Tempo de Resposta a Códigos**  
Descrição: O sistema deve permitir a avaliação do tempo de resposta ao código de emergência, o trajeto realizado pela equipe de atendimento e o tempo de chegada até o local do código.

&emsp;&emsp; **Regra de Negócio Relacionada:** Essa avaliação é fundamental para otimizar a resposta a códigos de emergência, garantir a eficiência da equipe e determinar pontos de fluxo lento.

&emsp;&emsp; **RF6: Portabilidade e Resistência do Dispositivo**  
Descrição: O dispositivo de _tag_ deve ser portátil, fácil de manipular e resistente às condições hospitalares.

&emsp;&emsp; **Regra de Negócio Relacionada:** O dispositivo deve ser projetado para suportar o uso constante.

&emsp;&emsp; **RF7: Prevenção de Esquecimento da _Tag_**  
 Descrição: O sistema deve abordar o problema de as pessoas não devolverem a _tag_ ao sair do hospital ou ao entrar em salas de equipamentos sensíveis, como tomógrafos e ressonância magnética.

&emsp;&emsp; **Regra de Negócio Relacionada:** É essencial implementar medidas que incentivem os portadores a devolver as _tags_ após o uso, ou que monitorem seu movimento para evitar perdas ou esquecimentos.

&emsp;&emsp; Esses requisitos funcionais servem como orientação durante o desenvolvimento do projeto, pois diminuem a chance de falhas no sistema e corroboram para que o sistema seja capaz de atender às expectativas estabelecidas.

### 3.3.2. Requisitos Não Funcionais

&emsp;&emsp; Os requisitos não funcionais são os requisitos que definem como um sistema deve se comportar em determinadas situações, independentemente das suas funcionalidades básicas. Eles estabelecem os atributos de qualidade do projeto, tais como desempenho, segurança, usabilidade, escalabilidade e manutenção. Os requisitos não funcionais são essenciais para garantir que o sistema atenda às necessidades e expectativas do cliente, bem como aos padrões de qualidade exigidos. No contexto do projeto IoT, onde se utiliza RFID para localizar, classificar e temporalizar pessoas, os requisitos não funcionais podem envolver aspectos como a precisão da leitura das etiquetas, a confiabilidade da comunicação entre os dispositivos, a proteção dos dados pessoais e a facilidade de integração com outras aplicações.

&emsp;&emsp;Veja a seguir os requisitos não funcionais do projeto JinWar:

<div align="center">
  <p><b>Quadro 2</b>- Requisitos não funcionais</b></p>

| Identificador | Categoria | Requisito |
| --- | --- | --- |
| RFN01 | **Performance** | - O sistema deve possuir baixa latência, com um tempo de resposta máximo de 500 milisegundos. |
| RFN02 | **Performance** | - O sistema deve ser capaz de informar a localização com precisão de 6 metros. |
| RFN03 | **Escalabilidade** | - O sistema deve ser economicamente viável para replicação e expansão. |
| RFN04 | **Adaptabilidade** | - O sistema deve funcionar em ambientes com diferentes características, incluindo temperaturas variadas, sinais intermitentes e em diferentes andares, bem como integrar com diferentes sistemas. |
| RFN05 | **Manutenção** | - O sistema deve registrar todas as atividades relevantes para possibilitar uma manutenção e depuração eficaz, como timestamp de registros de uso. |
| RFN06 | **Operabilidade** | - O sistema deve incluir ferramentas de monitoramento para acompanhar o desempenho e a disponibilidade do sistema. |
| RFN07 | **Segurança** | - O sistema deve exigir autenticação por senha para acessar e visualizar os dados de fluxo. |
| RFN08 | **Disponibilidade**  | - A solução IoT deve ser projetada para funcionar 24 horas por dia e 7 dias por semana, exceto nos períodos de manutenção programada. |
| RFN09 | **Recuperabilidade** | - O sistema deve realizar backups automáticos de dados e configurações, programados para ocorrer diariamente. |
| RFN10 | **Reusabilidade** | - O sistema deve ser projetado para permitir sua reutilização em diferentes contextos e projetos. |

  <p><b>Fonte:</b> elaboração por Jinwar.</p>
</div>

&emsp;&emsp; Diante dos requisitos não funcionais elencados, pode-se perceber que os mais críticos para o sucesso do projeto são os relacionados à performance e à disponibilidade do sistema. Esses requisitos exigem que o sistema seja capaz de fornecer uma resposta rápida e precisa aos usuários, bem como operar de forma contínua e ininterrupta. Esses desafios demandam uma solução IoT robusta, eficiente e confiável, que utilize tecnologias adequadas e otimizadas para o contexto do projeto.

### 3.3.4. Arquitetura da Solução

&emsp;&emsp;Com base nos requisitos levantados, a arquitetura da solução para o sistema começou a tomar forma. Em resposta ao RF1- Identificação do portador da Tag, a solução será fundamentada na utilização de sensores RFID, a fim de coletar os dados que permitem identificar os portadores da tag, sendo eles: nome, cargo, sexo, localização e horário da ativação.

&emsp;&emsp;A arquitetura da solução visa melhorar o entendimento do projeto, a partir de uma visão mais técnica sobre os componentes, tecnologias e fluxo de uso de cada parte. Considerando o entendimento de negócio, os requisitos funcionais e os requisitos não funcionais do projeto, foi feita a arquitetura da solução em blocos. Essa representação visual proporciona uma compreensão mais clara das interações entre os elementos, destacando a fluidez do fluxo de dados e as conexões cruciais que sustentam a funcionalidade global do sistema.

&emsp;&emsp;O diagrama de fluxo é uma importante ferramenta de visualização da arquitetura de uma solução computacional. Ele possibilita uma visão mais ampla do comportamento da solução e todas as etapas e tecnologias envolvidas.

&emsp;&emsp;A partir do diagrama de arquitetura a seguir, é possível identificar como o token rfid, o sensor, o microcontrolador ESP32, o MQTT Broker, o servidor, o banco de dados e o dashboard se relacionam no contexto da solução proposta.

<div align="center" >
  <p><b>Figura 16</b> - Arquitetura da Solução</p>
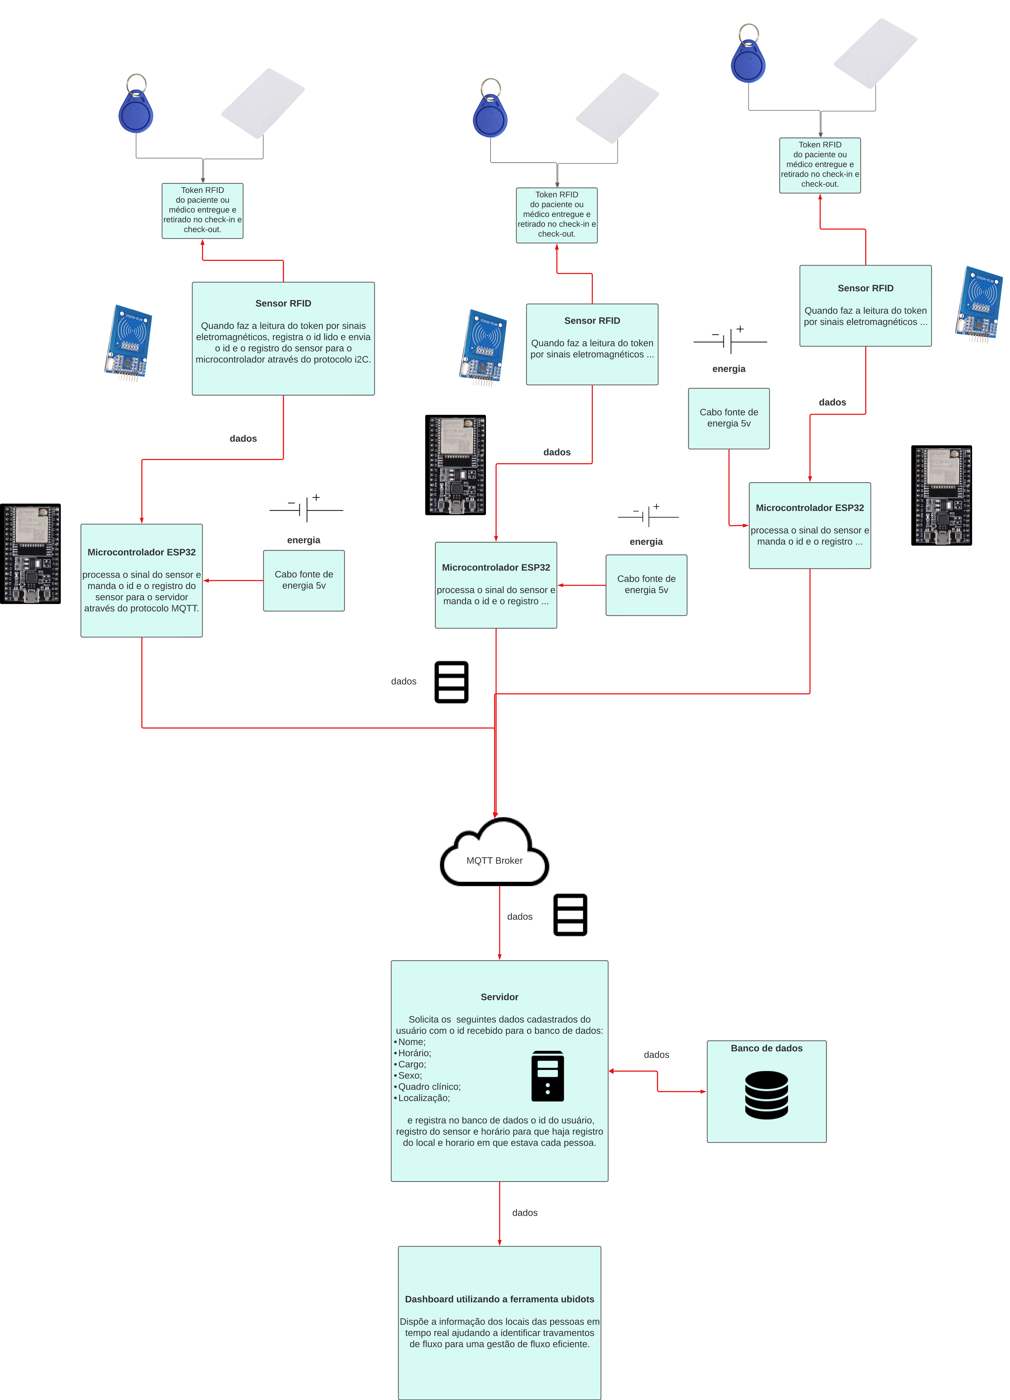
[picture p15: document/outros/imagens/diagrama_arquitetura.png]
Arquitetura da Solução
  
  <p>Fonte: elaboração por Jinwar.</p>
</div>

&emsp;&emsp;Para uma experiência mais visual da arquitetura com uma explicação guiada, assista ao vídeo a seguir.

<div align="center">
  <p><b>Video 1</b> - Arquitetura da Solução</p>
  <a href="https://www.youtube.com/watch?v=Ca8lY6PalLw">
    demonstração da Arquitetura da Solução
  </a>
  <p><b>Fonte:</b> elaboração por Jinwar.</p>
</div>

&emsp;&emsp;Como observado na figura 16, a arquitetura da solução aborda cada um dos requisitos funcionais e não funcionais da seguinte forma:

**Requisitos funcionais**:

- RF1: Identificação do portador da Tag:

&emsp;&emsp;A associação entre a tag registrada no sensor rfid e a informação do portador presente no banco de dados identifica o portador da tag.

- RF2: Rastreamento em tempo real:

&emsp;&emsp;A associação entre as informações coletadas pelo ESP32 e a dashboard permite o rastreamento em tempo real dentro do hospital.

- RF3: Avaliação de Tempos de Chegada e Saída:

&emsp;&emsp;Será possível avaliar os tempos de chegada e saída a partir dos dados de horário, local e id coletados e registrados no banco de dados que depois serão sujeitos a análise.

- RF4: Resposta a Códigos de Emergência:

&emsp;&emsp;O escopo atual da solução não soluciona o problema de resposta a código de emergência por enquanto, essa parte está em backlog.

- RF5: Avaliação de Tempo de Resposta a Códigos:

&emsp;&emsp;O escopo atual da solução não soluciona o problema de tempo de resposta a código de emergência por enquanto, essa parte está em backlog.

- RF6: Portabilidade e Resistência do Dispositivo:

&emsp;&emsp;A portabilidade e resistência do dispositivo são solucionadas através do uso de rfid que possui um token pequeno e revestido com plástico que pode ser higienizado.

- RF7: Prevenção de Esquecimento da Tag:

&emsp;&emsp;A tag está associada ao check-in e check-out do hospital. Dessa forma, o paciente vai devolver a tag no momento em que for fazer o check-out

**Requisitos não funcionais**:

- RFN01: O sistema deve possuir baixa latência, com um tempo de resposta máximo de 500 milisegundos(ms):

&emsp;&emsp;As conexões e protocolos utilizados na solução possuem baixa latência, o rfid tem latência menor que 100 ms, o ESP32 tem latência de 30 ms a 50 ms e, apesar de não ser possível precisar a latência do servidor a soma total provavelmente fica abaixo de 500 ms.

- RFN02: O sistema deve ser capaz de informar a localização com precisão de 6 metros:

&emsp;&emsp;A arquitetura de um ESP32 com sensor rfid por área possui uma precisão menor que 6 metros já que haverá pelo menos um ESP32 a cada 3m^2.

- RFN03: O sistema deve ser economicamente viável para replicação e expansão:

&emsp;&emsp;Todas as peças presentes na arquitetura possuem baixo custo.

- RFN04: O sistema deve funcionar em ambientes com diferentes características, incluindo temperaturas variadas, sinais intermitentes e em diferentes andares, bem como integrar com diferentes sistemas:

&emsp;&emsp;A solução é resistente a sinais intermitentes já que checa constantemente a localização dos ids e a variações de temperatura. O único sinal que pode interferir de maneira negativa são interferências no campo magnético. A integração do sistema será feita através do servidor e do banco de dados.

- RFN05: O sistema deve registrar todas as atividades relevantes para possibilitar uma manutenção e depuração eficaz, como timestamp de registros de uso:

&emsp;&emsp;O sistema registra o timestamp juntamente com o id.

- RFN06: O sistema deve incluir ferramentas de monitoramento para acompanhar o desempenho e a disponibilidade do sistema:

&emsp;&emsp;Um dashboard na plataforma ubidots será a ferramenta utilizada para monitoramento.

- RFN07: O sistema deve exigir autenticação por senha para acessar e visualizar os dados de fluxo:

&emsp;&emsp;A autenticação será realizada através da plataforma ubidots.

- RFN08: A solução IoT deve ser projetada para funcionar 24 horas por dia e 7 dias por semana, exceto nos períodos de manutenção programada:

&emsp;&emsp;Todos os componentes que dependem de fornecimento de energia elétrica estarão conectados a fontes o que previne a necessidade de recarga.

- RFN09: O sistema deve realizar backups automáticos de dados e configurações, programados para ocorrer diariamente:

&emsp;&emsp;O sistema salva todos os registros no banco de dados conforme aparecem.

- RFN10: O sistema deve ser projetado para permitir sua reutilização em diferentes contextos e projetos:

&emsp;&emsp;A arquitetura suporta a reutilização do projeto em qualquer contexto de rastreamento de localização em estabelecimentos comerciais com check-in e check-out.

&emsp;&emsp;Com base na análise da arquitetura, torna-se evidente que a abordagem adotada visa não apenas aprimorar a compreensão técnica do projeto, mas também a otimizar a relação entre seus componentes. A representação visual em blocos proporciona uma visão clara das conexões essenciais que sustentam a funcionalidade global do sistema. Essa estrutura promove um entendimento mais profundo das interações, também destacando a fluidez do fluxo de dados, formando assim, uma base sólida para a implementação bem-sucedida da solução proposta.

### 3.3.5. Arquitetura do Protótipo

&emsp;&emsp;O diagrama de blocos é um modelo que representa um sistema para facilitar seu entendimento, manutenção e modificação através de uma demonstração passo a passo da dos diferentes componentes físicos e digitais da solução assim como as tecnologias aliadas a esse processo.

&emsp;&emsp;A seguir estão representados dois diagramas de blocos da arquitetura da solução Jinwar. O primeiro representa o fluxo do rastreamento dos médicos e pacientes no hospital. O segundo, por sua vez, aponta o funcionamento da etapa de cadastro e devolução dos RFIDs associando o id ao paciente ou médico.

<div align="center">
  <p><b>Figura 17</b>- Fluxo do Rastreamento</b></p>
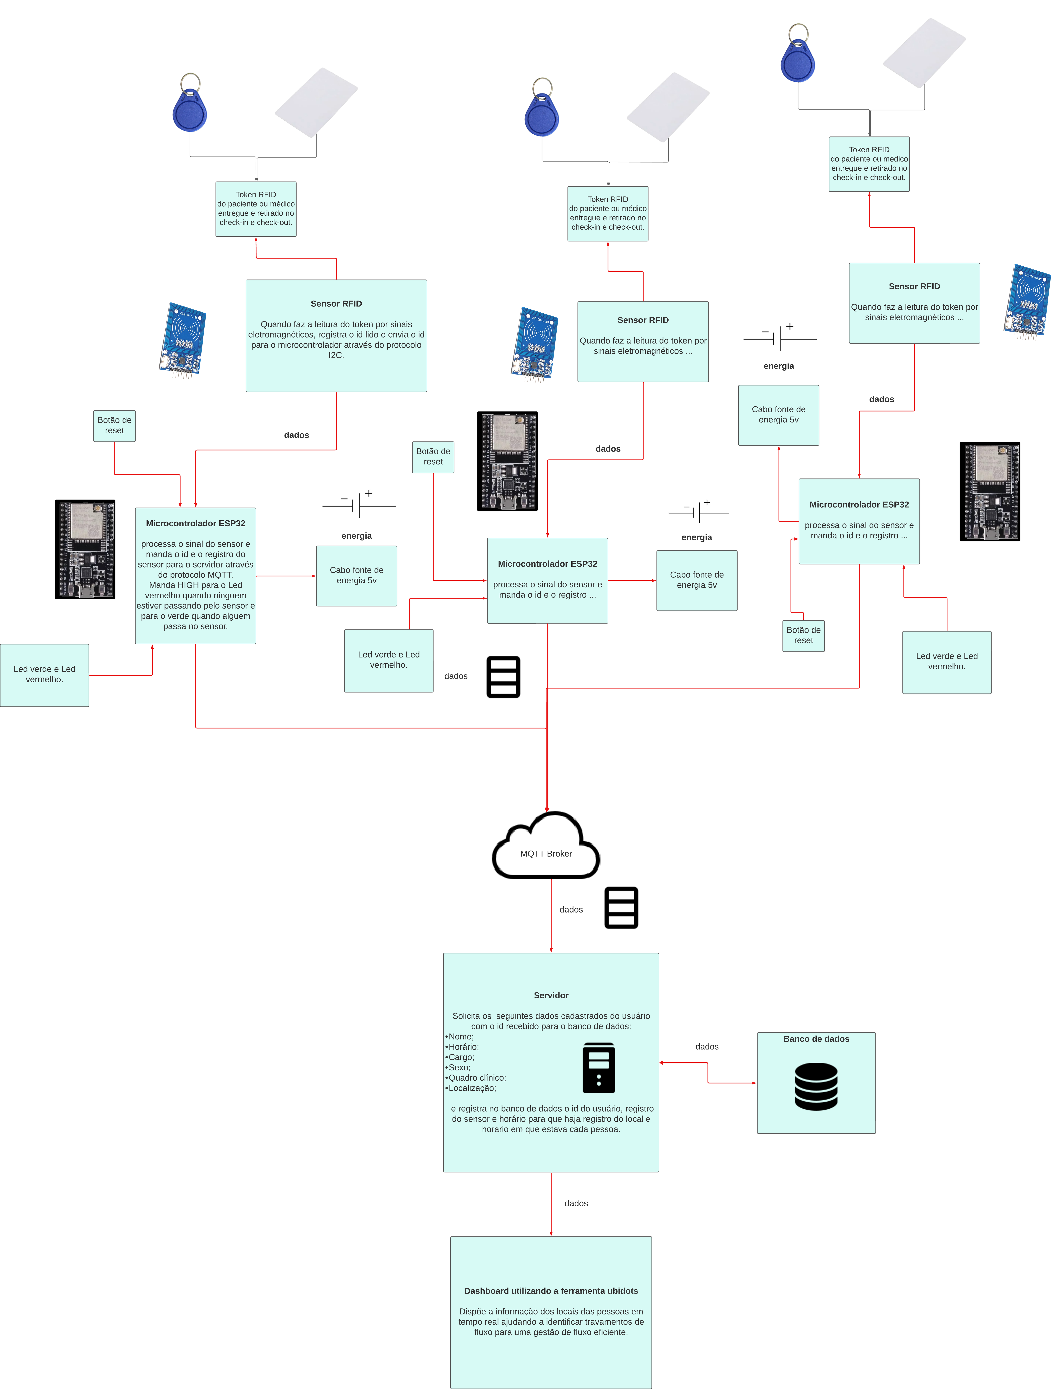
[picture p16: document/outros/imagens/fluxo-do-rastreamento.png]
fluxo do rastreamento
  
  <p><b>Fonte:</b> elaboração por Jinwar.</p>
</div>

<div align="center">
  <p><b>Figura 18</b>- Cadastro e Devolução dos RFIDs</b></p>
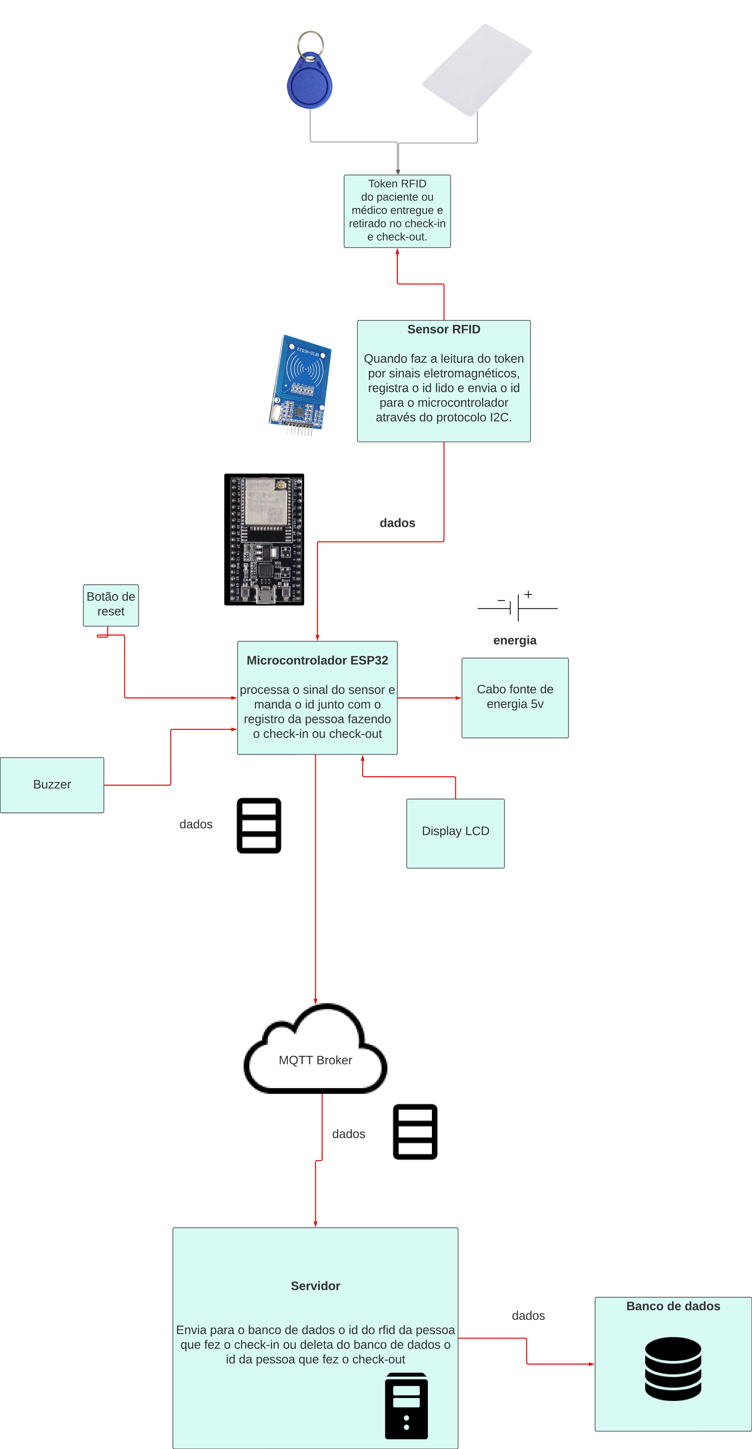
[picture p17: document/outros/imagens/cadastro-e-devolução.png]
Cadastro e Devolução dos RFIDs
  
  <p><b>Fonte:</b> elaboração por Jinwar.</p>
</div>
&emsp;&emsp;A seguir estão listados os componentes e conexões dos hardwares dos dois diagramas para facilitar a compreensão da parte física da solução.

Componentes do diagrama do sensor:

<div align="center">
  <p><b>Quadro 3</b>- Requisitos não funcionais</b></p>

| **Componente** | **Descrição** | **Tipo** |
| --- | --- | --- |
| ESP32 | Microcontrolador que opera os módulos do sistema | Microcontrolador ESP32 |
| Jumpers | Jumpers para conectar os módulos | Jumpers macho macho |
| Sensor RFID | Sensor para detectar as TAGs RFID | Módulo Sensor RFID MFRC522 13,56 MHZ |
| TAG RFID | TAGs RFID para pacientes e médicos | Tag RFID 13,56MHz |
| Botão | Botão para reset | Chave Táctil 6x6x5mm 4 Terminais |
| LED vermelho | LED vermelho para feedback visual | LED vermelho 5mm |
| LED verde | LED verde para feedback visual | LED verde 5mm |

  <p><b>Fonte:</b> elaboração por Jinwar.</p>
</div>

Conexões do diagrama do sensor:

- 3.3v sensor rfid - 3.3v ESP32
- rst sensor rfid - pino 22 ESP32
- gnd sensor rfid - gnd ESP32
- miso sensor rfid - pino 19 ESP32
- mosi sensor rfid - pino 23 ESP32
- sck sensor rfid - pino 18 ESP32
- sda sensor rfid - pino 21 ESP32
- botão - 3.3v ESP32
- botão - pino 33 ESP32
- led vermelho negativo - gnd ESP32
- led vermelho positivo - pino 26 ESP32
- led verde negativo - gnd ESP32
- led verde positivo - pino 27 ESP32

Componentes do diagrama do registrador:

<div align="center">
  <p><b>Quadro 4</b>- Requisitos não funcionais</b></p>

| **Componente** | **Descrição** | **Tipo** |
| --- | --- | --- |
| ESP32 | Microcontrolador que opera os módulos do sistema | Microcontrolador ESP32 |
| Jumpers | Jumpers para conectar os módulos | Jumpers macho macho |
| Sensor RFID | Sensor para detectar as TAGs RFID | Módulo Sensor RFID MFRC522 13,56 MHZ |
| TAG RFID | TAGs RFID para pacientes e médicos | Tag RFID 13,56MHz |
| Botão | Botão para reset | Chave Táctil 6x6x5mm 4 Terminais |
| Display LCD | Display LCD para feedback visual | Display LCD 16x2 (Azul) com Módulo Adaptador I2C |
| Buzzer | Buzzer para feedback sonoro | Buzzer 5V |

  <p><b>Fonte:</b> elaboração por Jinwar.</p>
</div>

Conexões do diagrama do registrador:

- 3.3v sensor rfid - 3.3v ESP32
- rst sensor rfid - pino 22 ESP32
- gnd sensor rfid - gnd ESP32
- miso sensor rfid - pino 19 ESP32
- mosi sensor rfid - pino 23 ESP32
- sck sensor rfid - pino 18 ESP32
- sda sensor rfid - pino 21 ESP32
- botão - 3.3v ESP32
- botão - pino 33 ESP32
- vcc lcd - 5v ESP32
- gnd lcd - gnd ESP32
- sda lcd - pino 4 ESP32
- scl lcd - pino 5 ESP32
- buzzer - pino 17 ESP32

&emsp;&emsp;Acesse o vídeo explicativo dos diagramas e do fluxo da solução Jinwar a seguir para uma explicação aprofundada.

<div align="center">
  <p><b>Vídeo 2</b> - Demonstração dos Diagramas e do fluxo da solução</p>
  <a href="https://youtu.be/Oxi_v7UXHtI">
    
  </a>
  <p><b>Fonte:</b> elaboração por Jinwar.</p>
</div>

&emsp;&emsp;Em conclusão, a representação em diagramas de blocos da arquitetura do sistema desempenha um papel crucial na compreensão e delineamento das complexidades envolvidas na arquitetura do sistema Jinwar. Ao apresentar uma representação visual passo a passo dos diferentes componentes físicos e digitais, esses diagramas proporcionam clareza e transparência na compreensão do fluxo de trabalho, especialmente nas etapas de rastreamento hospitalar e registro de RFIDs.
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

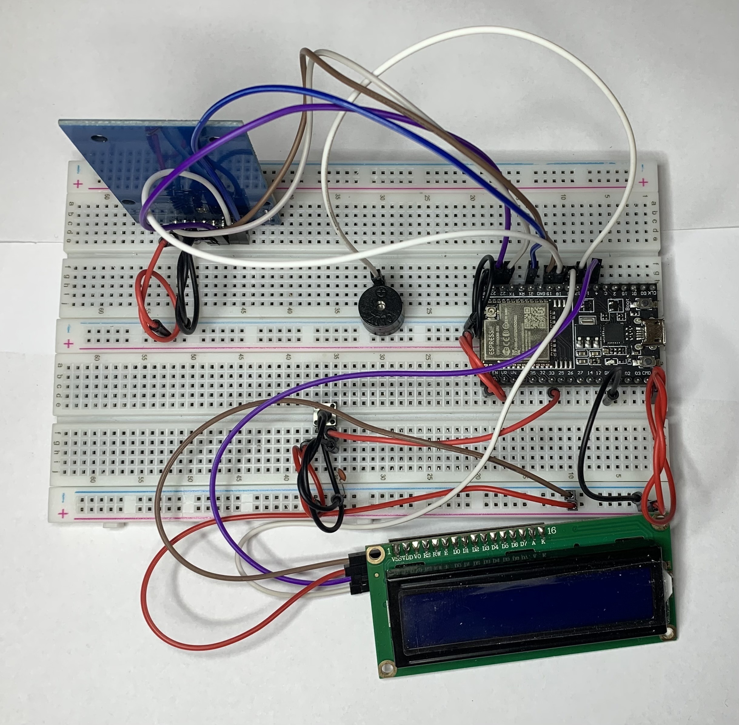
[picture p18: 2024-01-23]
document/outros/imagens/prototipo_fisico_cadastro.jpg

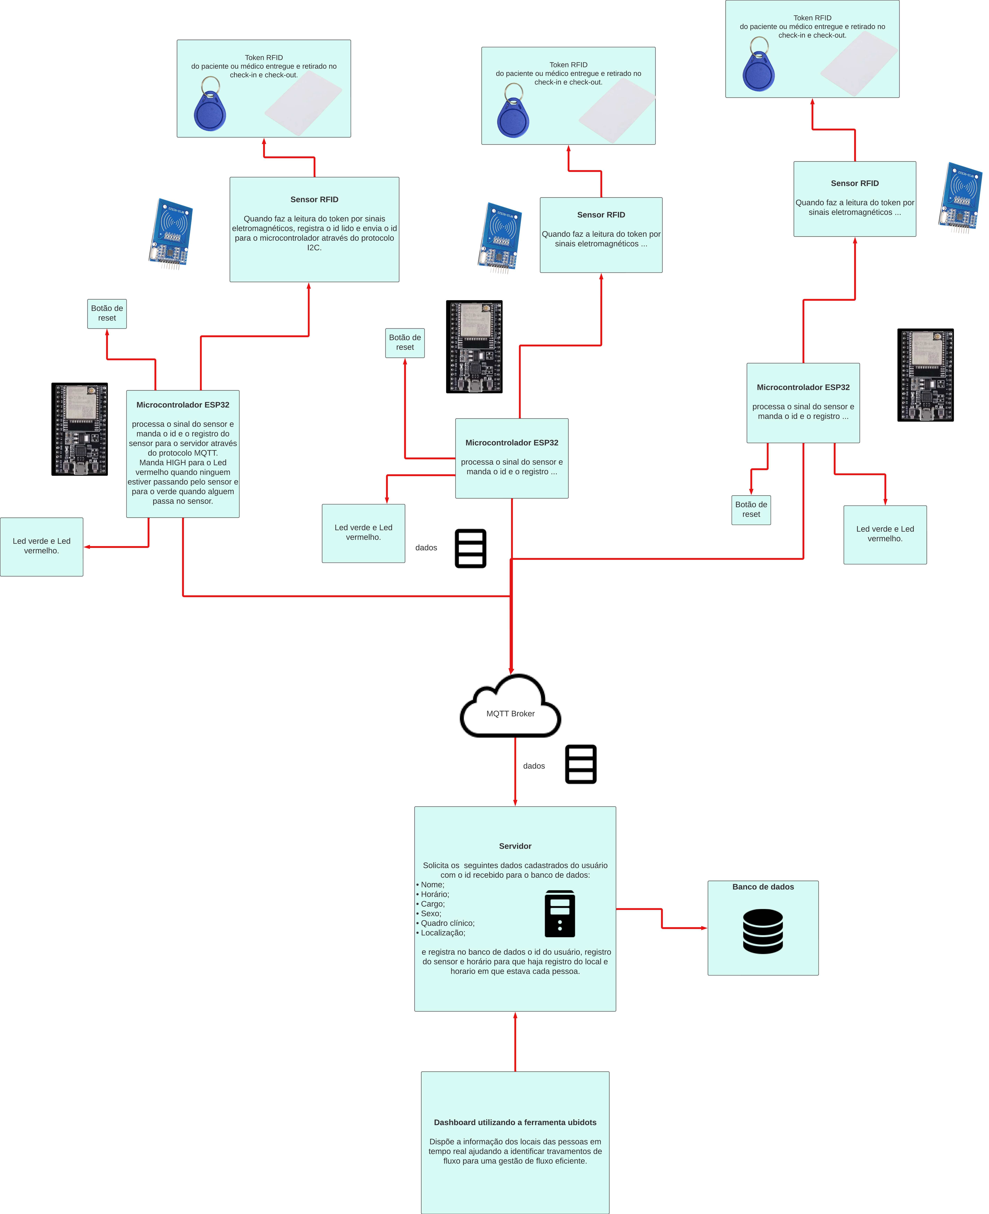
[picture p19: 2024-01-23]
document/outros/imagens/diagrama-refinado1.png

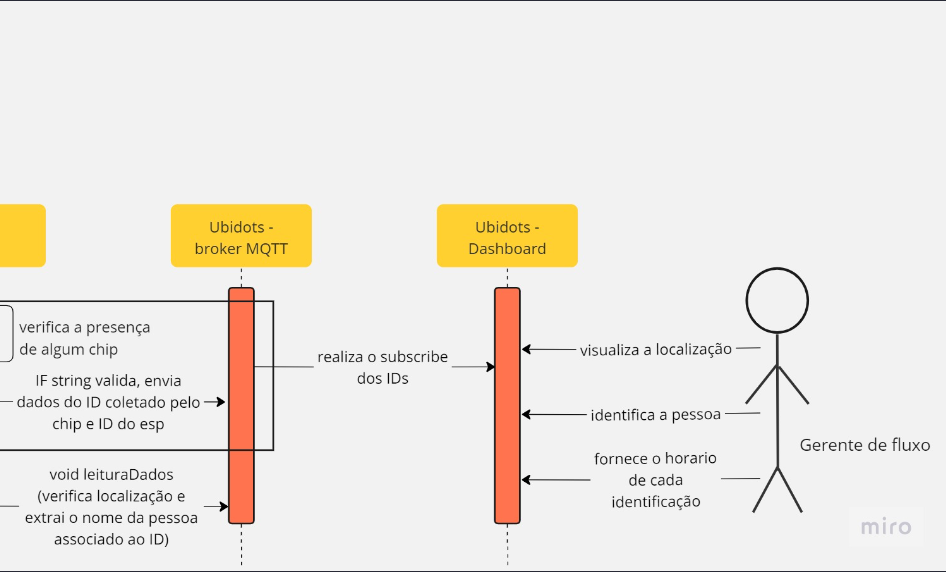
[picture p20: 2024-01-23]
document/outros/imagens/umlUbidots.png

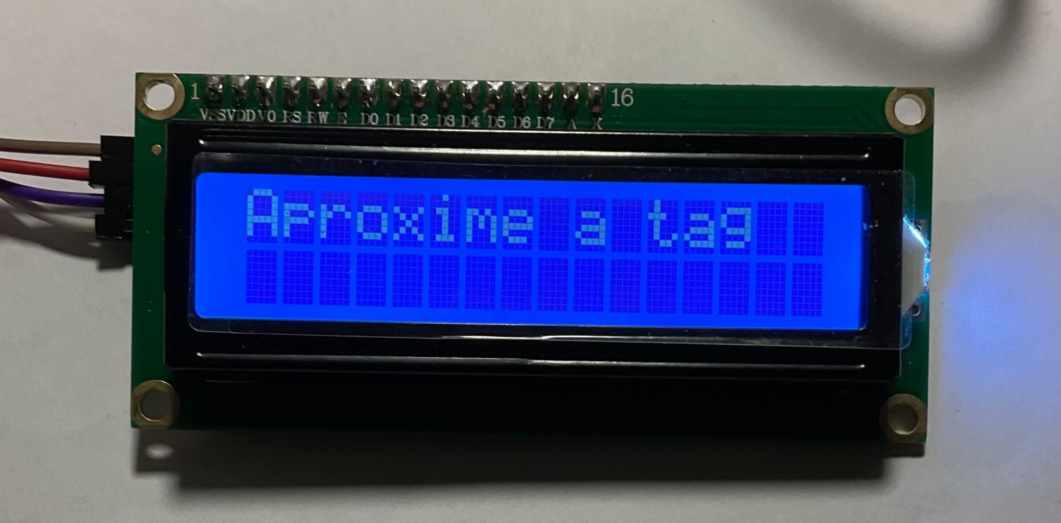
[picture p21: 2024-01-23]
document/outros/imagens/lcd_cadastro.jpg

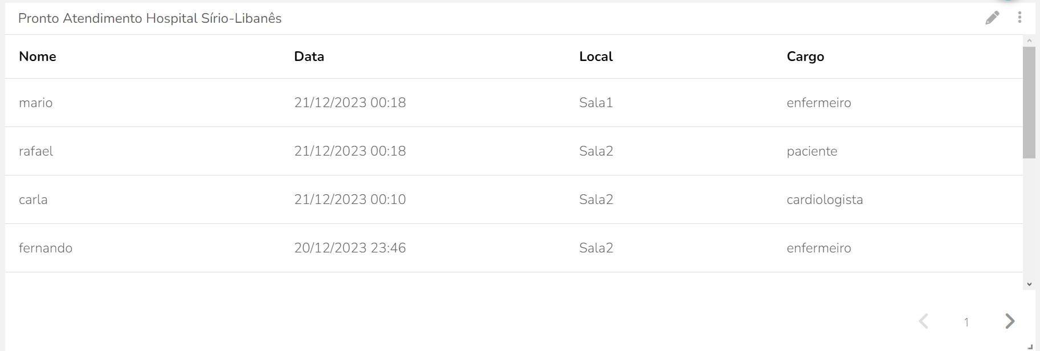
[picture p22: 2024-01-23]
document/outros/imagens/Ubidots.png

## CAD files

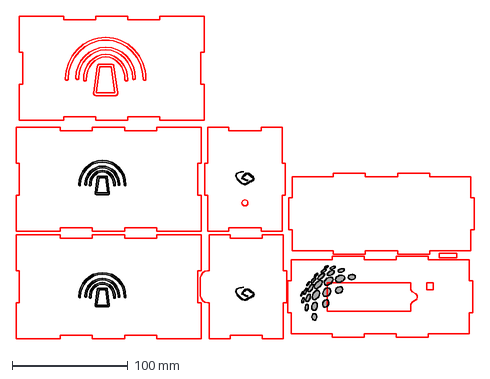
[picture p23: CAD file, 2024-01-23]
document/outros/case_box_cortes/Cortes_controlador.dxf
396.0 x 278.9 mm

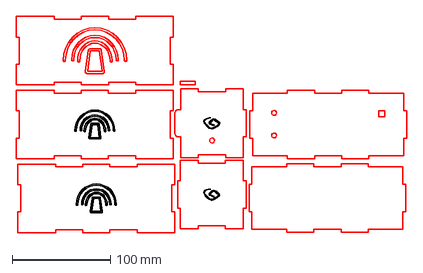
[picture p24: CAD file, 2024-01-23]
document/outros/case_box_cortes/Cortes_individual.dxf
397.9 x 220.7 mm

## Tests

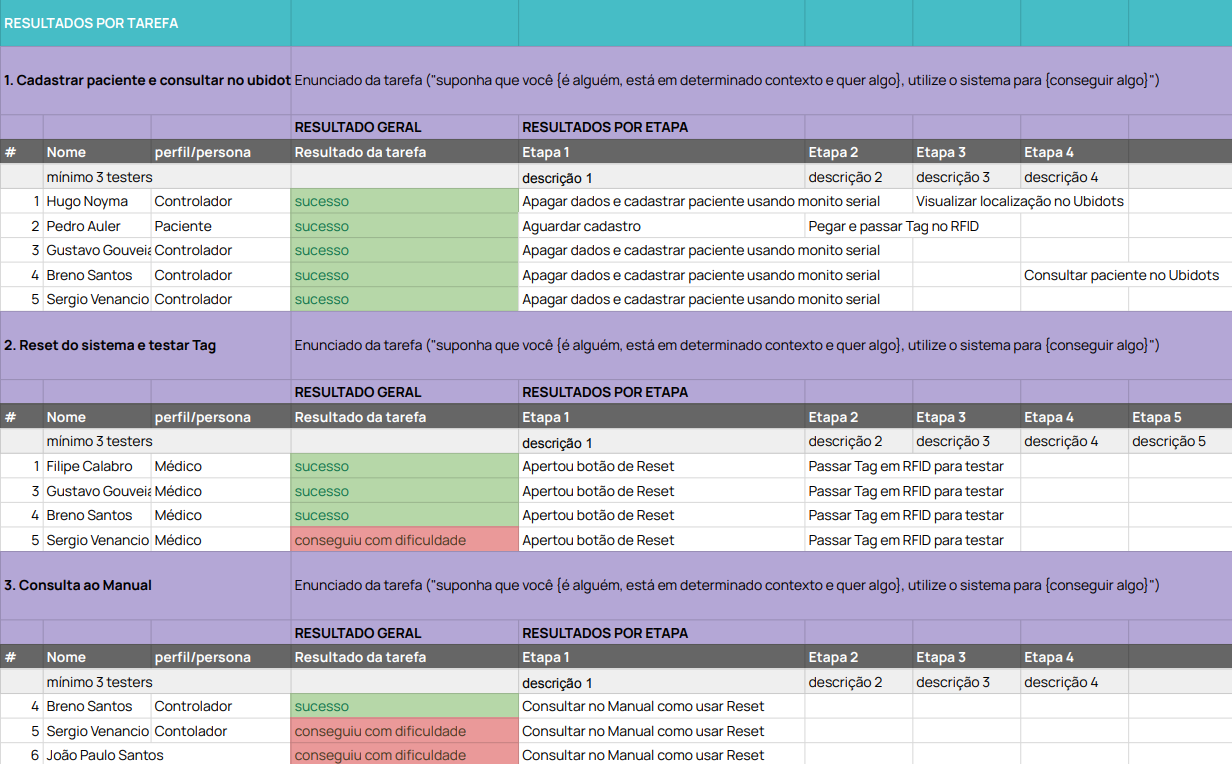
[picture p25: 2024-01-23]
document/outros/imagens/quadro1_testes.png

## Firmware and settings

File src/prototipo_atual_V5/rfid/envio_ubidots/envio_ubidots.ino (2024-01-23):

// Inclusion of necessary libraries for communication with the RFID, Wi-Fi, MQTT, and Ubidots modules
#include <WiFi.h>
#include <MFRC522.h>
#include <SPI.h>
#include "UbidotsEsp32Mqtt.h"
#include <PubSubClient.h>
#include <map>

// Definition of constants for connection to Ubidots and Wi-Fi network
const char *UBIDOTS_TOKEN = "BBUS-Wr0Chf75jREI6GgNS2a6PZvQqvssaE";
const char *WIFI_SSID = "SHARE-RESIDENTE";
const char *WIFI_PASS = "Share@residente23";
const char *DEVICE_LABEL = "sala";
const char *VARIABLE_LABEL = "consultorio";

// Variables for time control
unsigned long timer;
const int PUBLISH_FREQUENCY = 5000; // Time interval for data publication

// Define the time duration in milliseconds that the LED will be on
const int LED_ON_TIME = 1000; // 1000 ms = 1 second

// Variable to control the LED timer
unsigned long ledTimer;

// Ubidots client initialization
Ubidots ubidots(UBIDOTS_TOKEN);

// Definition of pins used for the RFID module
#define SS_PIN    21
#define RST_PIN   22

// Definition of the button pin
#define BUTTON_PIN 33

// Definition of LED pins
#define LED_VERDE 27
#define LED_VERMELHO 26

String cargo = "";
String nomePessoa = "";
String localizacao = "";
String esp32Id = WiFi.macAddress();

// Add MAC addresses associated with each location
String recepcaoMAC = "A8:42:E3:56:A4:20";
String sala1MAC = "B4:8A:0A:AD:A8:64";
String sala2MAC = "48:E7:29:8B:DB:C8";
// Object to store the authentication key of the RFID card
MFRC522::MIFARE_Key key;

// Object to interact with the RFID module MFRC522
MFRC522 mfrc522(SS_PIN, RST_PIN);

// Function called when a message is received by the MQTT client
void callback(char* topic, byte* payload, unsigned int length) {
    Serial.print("Message arrived [");
    Serial.print(topic);
    Serial.print("] ");
    for (int i = 0; i < length; i++) {
        Serial.print((char)payload[i]);
    }
    Serial.println();
}

// Global variables
std::map<String, std::map<String, int>> contagemPorLocalizacao;
std::map<String, std::map<String, unsigned long>> ultimoTempoPorLocalizacao;

// Function to check if a new ID can be counted
bool podeContabilizar(String localizacao, unsigned long tempoAtual) {
    if (ultimoTempoPorLocalizacao.find(localizacao) != ultimoTempoPorLocalizacao.end()) {
        if (ultimoTempoPorLocalizacao[localizacao].find(localizacao) != ultimoTempoPorLocalizacao[localizacao].end()) {
            unsigned long ultimoTempo = ultimoTempoPorLocalizacao[localizacao][localizacao];
            return (tempoAtual - ultimoTempo) > 40000;  // Check if the interval is greater than 40 seconds
        }
    }
    return true;
}

// Function to increment the count of IDs for a specific location
void incrementarContagem(String localizacao, unsigned long tempoAtual) {
    if (podeContabilizar(localizacao, tempoAtual)) {
        // Update the last recorded time for the location
        if (ultimoTempoPorLocalizacao.find(localizacao) != ultimoTempoPorLocalizacao.end()) {
            ultimoTempoPorLocalizacao[localizacao][localizacao] = tempoAtual;
        } else {
            std::map<String, unsigned long> novoMap;
            novoMap[localizacao] = tempoAtual;
            ultimoTempoPorLocalizacao[localizacao] = novoMap;
        }
        // Increment the count for the specific location

        if (contagemPorLocalizacao.find(localizacao) != contagemPorLocalizacao.end()) {
            if (contagemPorLocalizacao[localizacao].find(localizacao) != contagemPorLocalizacao[localizacao].end()) {
                contagemPorLocalizacao[localizacao][localizacao]++;
            } else {
                contagemPorLocalizacao[localizacao][localizacao] = 1;
            }
        } else {
            contagemPorLocalizacao[localizacao][localizacao] = 1;
        }
    } else {
        Serial.println("ID já contabilizado recentemente. Ignorando...");
    }
}

// Function to print the current count by location
void imprimirContagem() {
    Serial.println("Contagem por Localizacao:");
    for (auto const& pair : contagemPorLocalizacao) {
        Serial.print(pair.first);
        Serial.print(": ");
        for (auto const& innerPair : pair.second) {
            Serial.print(innerPair.first);
            Serial.print(" - ");
            Serial.print(innerPair.second);
            Serial.print(", ");
        }
        Serial.println();
    }
}

void resetProgram() {
    // Reinitialize variables, states, and possibly call setup()
    return;
}

// Initial program setup
void setup() {
    pinMode(LED_VERMELHO, OUTPUT);
    pinMode(LED_VERDE, OUTPUT);
    pinMode(BUTTON_PIN, INPUT_PULLUP); // Configure the button pin as input with pull-up
    Serial.begin(115200); // Start serial communication
    SPI.begin(); // Start SPI communication for the RFID module
    mfrc522.PCD_Init(); // Initialize the RFID module
    ubidots.setDebug(true);
    ubidots.connectToWifi(WIFI_SSID, WIFI_PASS);
    ubidots.setCallback(callback);
    ubidots.setup();
    ubidots.reconnect();
    timer = millis();// Initialize the timer
    Serial.println("Leitura: Aproxime o seu cartão do leitor...");
}
// Main program loop
void loop() {
    atualizarLed();// Place this at the beginning of the loop to ensure it is always executed
    // Check if a new RFID card is present and can be read
    if (!mfrc522.PICC_IsNewCardPresent() || !mfrc522.PICC_ReadCardSerial()) {
        digitalWrite(LED_VERMELHO, HIGH);
        return;
    } else {
        digitalWrite(LED_VERDE, LOW);// Turn off the Green LED
        acenderLed();// Turn on the Green LED and start the timer
    }
    
    leituraDados();// Read data from the RFID card
    mfrc522.PICC_HaltA(); // Put the card in "halt" state
    mfrc522.PCD_StopCrypto1();// Deactivate encryption for card communication
    // Reconnect to Ubidots if necessary and publish the read data
    if (!ubidots.connected()) {
        ubidots.reconnect();
    }
    
    if ((millis() - timer) > PUBLISH_FREQUENCY) {
        // Check if the string contains a valid name and publish to Ubidots
        if (nomePessoa.length() > 0) {

            // Check the MAC address to determine the location
            if (esp32Id.equals(recepcaoMAC)) {
                localizacao = "Recepcao";
            } else if (esp32Id.equals(sala1MAC)) {
                localizacao = "Sala1";
            } else if (esp32Id.equals(sala2MAC)) {
                localizacao = "Sala2";
            } else {
                localizacao = "Desconhecida";
            }

            incrementarContagem(localizacao, millis());


            char context[100];
            snprintf(context, sizeof(context), "\"nome\":\"%s\",\"localizacao\":\"%s\",\"cargo\":\"%s\"", nomePessoa.c_str(), localizacao, cargo.c_str());
            Serial.println(context);
            ubidots.add(VARIABLE_LABEL, 1, context);
            ubidots.publish(DEVICE_LABEL);
        
        } else {
           Serial.println("Nome Pessoa está vazio, nada será publicado.");
        }

        // Print the current count
        imprimirContagem();

        timer = millis();
}

    ubidots.loop(); // Keep the MQTT connection active
}
// Function to turn on the LED and start the timer
void acenderLed() {
    digitalWrite(LED_VERDE, HIGH);// Turn on the Green LED
    ledTimer = millis();// Start the timer
}
// Function to check and update the LED state
void atualizarLed() {
    if (millis() - ledTimer < LED_ON_TIME) {
        digitalWrite(LED_VERDE, HIGH);// Turn on the Green LED
        digitalWrite(LED_VERMELHO, LOW);// Turn off the Red LED
    } else {
        digitalWrite(LED_VERDE, LOW);// Turn off the Green LED after the specified time
        digitalWrite(LED_VERMELHO, HIGH); // Reactivate the Red LED
    }
}

void leituraDados() {
    // Print card details to the serial console
  mfrc522.PICC_DumpDetailsToSerial(&(mfrc522.uid));
    // Set the default authentication key for all blocks (FF FF FF FF FF FF)
  for (byte i = 0; i < 6; i++) {
    key.keyByte[i] = 0xFF;
  }
 // Buffer to store the read data from the card
 // Make sure to clear the buffer to avoid garbage from previous reads
  byte buffer[18];
  byte bufferCargo[18];
  memset(buffer, 0, sizeof(buffer));// Initialize the buffer with zeros
  byte bloco = 1; // Set the block to be read
  byte blocoCargo = 2; 
  byte tamanho = sizeof(buffer);// Buffer size
    // Authenticate the block for operation
  // Authenticate the block for operation
  MFRC522::StatusCode status = mfrc522.PCD_Authenticate(
      MFRC522::PICC_CMD_MF_AUTH_KEY_A, bloco, &key, &(mfrc522.uid));


  // Check if authentication was successful
  if (status != MFRC522::STATUS_OK) {
      Serial.print(F("Authentication failed: "));
      Serial.println(mfrc522.GetStatusCodeName(status));
      return;
  }

  // Read data from the authenticated block
  status = mfrc522.MIFARE_Read(bloco, buffer, &tamanho);

  // Check if reading was successful
  if (status != MFRC522::STATUS_OK) {
      Serial.print(F("Reading failed: "));
      Serial.println(mfrc522.GetStatusCodeName(status));
      return;
  }

  // Authenticate the next block for operation
  MFRC522::StatusCode status2 = mfrc522.PCD_Authenticate(
      MFRC522::PICC_CMD_MF_AUTH_KEY_A, blocoCargo, &key, &(mfrc522.uid));

  // Check if authentication was successful for the second block
  if (status2 != MFRC522::STATUS_OK) {
      Serial.print(F("Authentication failed for blocoCargo: "));
      Serial.println(mfrc522.GetStatusCodeName(status2));
      return;
  }

  // Read data from the authenticated blocoCargo
  status2 = mfrc522.MIFARE_Read(blocoCargo, bufferCargo, &tamanho);

  // Check if reading was successful for blocoCargo
  if (status2 != MFRC522::STATUS_OK) {
      Serial.print(F("Reading failed for blocoCargo: "));
      Serial.println(mfrc522.GetStatusCodeName(status2));
      return;

    } else {
      nomePessoa = "";  // Clear the current string
      for (int i = 0; i < 16; i++) {// Assume the name is in the first 16 bytes of the buffer
              // Add only printable ASCII characters
        if (buffer[i] >= 32 && buffer[i] <= 126) {
          nomePessoa += (char)buffer[i];
        } else if (buffer[i] == '\0') {
          break;// If a null byte is encountered, stop adding
        }
      nomePessoa.trim();// Remove whitespace from the beginning and end
          // Print the person's name or indicate if it's empty
      if (nomePessoa.length() > 0) {
        Serial.print(F("Nome no Cartão: "));
        Serial.println(nomePessoa);
        } 
      }
    }
    
      cargo = "";
      for (int i = 0; i < 16; i++) {// Assume the name is in the first 16 bytes of the buffer
              // Add only printable ASCII characters
        if (bufferCargo[i] >= 32 && bufferCargo[i] <= 126) {
          cargo += (char)bufferCargo[i];
        } else if (bufferCargo[i] == '\0') {
          break;// If a null byte is encountered, stop adding
        }
      }
      
      cargo.trim();// Remove whitespace from the beginning and end
          // Print the person's name or indicate if it's empty
      if (cargo.length() > 0) {
        Serial.print(F("Cargo: "));
        Serial.println(cargo);
      } 
        // Print the location or indicate if it's empty
      if (localizacao.length() > 0) {
        Serial.print(F("Localizacao atual: "));
        Serial.println(localizacao);
      } else {
        Serial.println(F("Cartão vazio"));
      }
    
    // Check if the button was pressed
    if (digitalRead(BUTTON_PIN) == LOW) {
      // Call the program reset function
      resetProgram();
    }
    // Print the current count
    imprimirContagem();

      // Finish reading the RFID card
    mfrc522.PICC_HaltA();
    mfrc522.PCD_StopCrypto1();
  }

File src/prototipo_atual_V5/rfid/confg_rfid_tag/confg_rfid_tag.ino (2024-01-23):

#include <MFRC522.h> //biblioteca responsável pela comunicação com o módulo RFID-RC522
#include <SPI.h> //biblioteca para comunicação do barramento SPI
#include <Wire.h>  // comunicação I2C
#include <LiquidCrystal_I2C.h>  // Biblioteca do display LCD com I2C

//RFID
#define SS_PIN    21
#define RST_PIN   22
#define SIZE_BUFFER     18
#define MAX_SIZE_BLOCK  16
//Definições para o display LCD (adapte conforme necessário)
#define I2C_ADDR    0x27  // Endereço do dispositivo I2C
#define LCD_COLS    16    // Número de colunas do LCD
#define LCD_ROWS    2     // Número de linhas do LCD
#define LCD_SDA     4
#define LCD_SCL     5

// Definição do pino do botão
#define BUTTON_PIN 33
// Definição do pino do buzzer
#define BUZZER_PIN 17
//esse objeto 'chave' é utilizado para autenticação
MFRC522::MIFARE_Key key;
//código de status de retorno da autenticação
MFRC522::StatusCode status;
// Definicoes pino modulo RC522
MFRC522 mfrc522(SS_PIN, RST_PIN);
LiquidCrystal_I2C lcd(I2C_ADDR, LCD_COLS, LCD_ROWS);

//menu para escolha da operação
int menu()
{
  Serial.println(F("\nEscolha uma opção:"));
  //Serial.println(F("0 - Leitura de Dados"));
  Serial.println(F("1 - Gravação de Dados\n"));
  Serial.println(F("2 - Limpar Dados da Tag\n"));
  //fica aguardando enquanto o usuário nao enviar algum dado
  while(!Serial.available()){};
  //recupera a opção escolhida
  int op = (int)Serial.read();
  //remove os proximos dados (como o 'enter ou \n' por exemplo) que vão por acidente
  while(Serial.available()) {
    if(Serial.read() == '\n') break;
    Serial.read();
  }
  return (op-48);//do valor lido, subtraimos o 48 que é o ZERO da tabela ascii
}

void setup() {
  pinMode(BUTTON_PIN, INPUT_PULLUP); // Configura o pino do botão como entrada com pull-up
  Wire.begin(LCD_SDA, LCD_SCL); // Inicializa a comunicação I2C com os pinos SDA e SCL
  // Inicia a serial
  Serial.begin(9600);
  SPI.begin(); // Init SPI bus
  // Inicia MFRC522
  mfrc522.PCD_Init();
  // Inicializa o LCD
  lcd.init();  // Inicializa o LCD
  lcd.backlight();  // Ativa a luz de fundo
  lcd.setCursor(0, 0);  // Define o cursor no início do display
  lcd.print("Aproxime a tag");  // Exibe a mensagem inicial
  // Mensagens iniciais no serial monitor
  Serial.println("Aproxime o seu cartao do leitor...");
  Serial.println();
}

void resetProgram() {
    // Reinicialize variáveis, estados, e possivelmente chame setup()
}

void loop() {
  // Aguarda a aproximacao do cartao e verifica se há cartão
  if (!mfrc522.PICC_IsNewCardPresent() || !mfrc522.PICC_ReadCardSerial()) {
    // Se nenhum cartão estiver presente, exibe a mensagem no LCD
    exibirMensagemAproxime();
    return;
  }
  // Verifica se o botão foi pressionado
    if (digitalRead(BUTTON_PIN) == LOW) {
        // Chama a função de reset do programa
        resetProgram();
    }
  // Faz a leitura dos dados
  leituraDados();
}
void exibirMensagemAproxime() {
  lcd.clear();  // Limpa o display LCD
  lcd.setCursor(0, 0);  // Define o cursor no início do display
  lcd.print("Aproxime a tag");  // Exibe a mensagem inicial
}
//faz a leitura dos dados do cartão/tag
void leituraDados() {
  mfrc522.PICC_DumpDetailsToSerial(&(mfrc522.uid));
  for (byte i = 0; i < 6; i++) {
    key.keyByte[i] = 0xFF;
  }
  byte buffer[SIZE_BUFFER] = {0};
  byte bloco = 1;
  byte tamanho = SIZE_BUFFER;
  status = mfrc522.PCD_Authenticate(MFRC522::PICC_CMD_MF_AUTH_KEY_A, bloco, &key, &(mfrc522.uid));
  if (status != MFRC522::STATUS_OK) {
    Serial.print(F("Authentication failed: "));
    Serial.println(mfrc522.GetStatusCodeName(status));
    return;
  }
  status = mfrc522.MIFARE_Read(bloco, buffer, &tamanho);
  if (status != MFRC522::STATUS_OK) {
    Serial.print(F("Reading failed: "));
    Serial.println(mfrc522.GetStatusCodeName(status));
    return;
  }
  Serial.print(F("\nDados bloco ["));
  Serial.print(bloco);
  Serial.print(F("]: "));
  for (uint8_t i = 0; i < MAX_SIZE_BLOCK; i++) {
    Serial.write(buffer[i]);
  }
  Serial.println(" ");

  // Lendo o bloco 2 para obter o cargo
  byte blocoCargo = 2; // Bloco onde o cargo está armazenado
  byte bufferCargo[MAX_SIZE_BLOCK] = {0}; // Buffer para armazenar os dados do cargo
  status = mfrc522.PCD_Authenticate(MFRC522::PICC_CMD_MF_AUTH_KEY_A, blocoCargo, &key, &(mfrc522.uid));
  if (status != MFRC522::STATUS_OK) {
    Serial.print(F("Authentication failed for cargo: "));
    Serial.println(mfrc522.GetStatusCodeName(status));
    return;
  }

  status = mfrc522.MIFARE_Read(blocoCargo, bufferCargo, &tamanho);
  if (status != MFRC522::STATUS_OK) {
    Serial.print(F("Reading cargo failed: "));
    Serial.println(mfrc522.GetStatusCodeName(status));
    return;
  }

  // Exibindo o cargo no monitor serial
  Serial.print(F("Cargo: "));
  for (uint8_t i = 0; i < MAX_SIZE_BLOCK; i++) {
    Serial.write(bufferCargo[i]);
  }
  Serial.println();
  // Verifica se os dados lidos são vazios
  bool dadosVazios = true;
  for (uint8_t i = 0; i < MAX_SIZE_BLOCK; i++) {
    if (buffer[i] != 0) {
      dadosVazios = false;
      break;
    }
  }
    // No final da função leituraDados(), após ler os dados do nome e do cargo:
    exibirDados(buffer, bufferCargo);
  // Mostra as opções dependendo se os dados estão vazios ou não
  if (dadosVazios) {
    Serial.println(F("Dados vazios na tag."));
    Serial.println(F("Opções disponíveis:"));
    Serial.println(F("1 - Gravar Dados"));
    Serial.println(F("2 - Limpar Dados da Tag"));
  } else {
    Serial.println(F("Opções disponíveis:"));
    Serial.println(F("1 - Gravar Dados"));
    Serial.println(F("2 - Limpar Dados da Tag"));
  }
  int opcao = menu();
  if (dadosVazios) {
    if (opcao == 1) {
      gravarDados();
    } else if (opcao == 2) {
      limparDados();
    } else {
      Serial.println(F("Opção inválida."));
    }
  } else {
    if (opcao == 0) {
      leituraDados();
    } else if (opcao == 1) {
      gravarDados();
    } else if (opcao == 2) {
      limparDados();
    } else {
      Serial.println(F("Opção inválida."));
    }
  }
  mfrc522.PICC_HaltA();
  mfrc522.PCD_StopCrypto1();
}
void exibirDados(byte *bufferNome, byte *bufferCargo) {
  lcd.clear();  // Limpa o display LCD
  lcd.setCursor(0, 0);  // Define o cursor na primeira linha do display

  // Exibe o nome na primeira linha
  lcd.print("Nome:");
  for (uint8_t i = 0; i < MAX_SIZE_BLOCK; i++) {
    if (bufferNome[i] != 0) {
      lcd.write(bufferNome[i]);
    }
  }

  // Exibe o cargo na segunda linha
  lcd.setCursor(0, 1);  // Move o cursor para a segunda linha
  lcd.print("Cargo:");
  for (uint8_t i = 0; i < MAX_SIZE_BLOCK; i++) {
    if (bufferCargo[i] != 0) {
      lcd.write(bufferCargo[i]);
    }
  }
}
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

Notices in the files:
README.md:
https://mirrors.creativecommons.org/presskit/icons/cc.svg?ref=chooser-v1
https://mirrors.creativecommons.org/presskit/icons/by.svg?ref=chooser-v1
